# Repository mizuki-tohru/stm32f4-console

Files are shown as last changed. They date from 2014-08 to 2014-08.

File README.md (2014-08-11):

This project is the palm size console with LCD and a keyboard. 
This uses STM32F4 microcomputer. This supports a 400x240-dot mono LCD, keyboard, CMOS, RS422, and Bluetooth serial communication. Moreover, this supports analog inputs. 
Charge of the li-po battery using USB, and high-speed access to a microSD card are also possible. 
A console carries extended BASIC of a uBASIC base. BASIC supports access to the FAT filesystem to microSD, bitmap drawing, analog inputs, and serial port input and output. 

このプロジェクトは、LCDとキーボードを持つ、てのひらサイズのコンソールを自作する試みです。
STM32F4マイコンを用い、400x240ドットモノクロ液晶とキーボード、CMOS、RS422、そしてBluetoothシリアル通信をサポートします。また3チャンネルのアナログ入力をサポートします。
USBコネクタを用いたリチウムポリマバッテリの充電と、microSDカードへの高速なアクセスも可能です。
コンソールはuBasicベースの拡張BASICを搭載します。BASICからmicroSDへのFATバイルシステムへのアクセス、ビットマップ描画、アナログ入力及びシリアルポート入出力をサポートします。

フォント作成にはrubyと東雲フォントが必要です。単体テスト用にcunitを使用していますが、テストを行わないのであれば必要ありません。

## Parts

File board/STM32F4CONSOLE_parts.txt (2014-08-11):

U1       	STM32F405RGT6  		MPUARM Cortex-M4 64Pin 		Digi-key	1184円
U2       	DM3AT-SF-PEJ		MicroSDカードソケット		秋月	140円
U4      	TAR5SB33      		3.3Vレギュレータ			秋月	10個280円
U6			FH12-10S-0.5SH     	液晶コネクタ				Digi-key	217円
D1			SS2040FL			ショットキーバリアダイオード秋月	20個300円
D2,D3,D4,D5,D6	
			1SS352    	    	ショットキーバリアダイオード秋月	40個200円
								
X1       	MUSB-5B-NE-S175		USBminiB基板実装コネクタ	秋月	2個100円
L1,L2,L3,L4 BLM21PG331			チップインダクタ			秋月	25個100円
Q1       	8MHz           		水晶発振子HC49/S型			秋月	10個400円
Q2       	32.768kHz      		水晶発振子TC26H型			秋月	4個100円
								
LED1,2,3						チップLED 0603				秋月	20個200円
Push SW1～43	                SKRPACE010 タクトスイッチ	秋月	5個100円
C1,C2    	22pF           		積層セラミックコンデンサ　0603 千石	10個50円
C3,C4    	5pF            		積層セラミックコンデンサ　0603 鈴商	10個100円
C9,C16,C20,C23,C25,C26,C27,C28	
			0.01uF      		積層セラミックコンデンサ　0603 千石	10個50円
C5,C10,C11,C17,C29	
			0.1uF          		積層セラミックコンデンサ　0603 千石	10個50円
C39      	0.33uF         		積層セラミックコンデンサ　0805 鈴商	10個100円
C8			1uF            	 	積層セラミックコンデンサ　0603 秋月	100個200円
C13,C18,C19 1uF            		積層セラミックコンデンサ　2012 鈴商	10個100円
C6,C7,C15   2.2uF          		積層セラミックコンデンサ　0805 鈴商	10個100円
C14			4.7uF				積層セラミックコンデンサ　2012 秋月	40個200円
C30			10uF           		積層セラミックコンデンサ　3216 秋月	8個100円
C12			47uF           		積層セラミックコンデンサ　3225 秋月	5個200円
								スライドスイッチ			千石	70円
R5,R6,R7,R8,R9,R10	
			22Ω             	抵抗 	603					千石	10個50円
R24,R25		33Ω				抵抗 	603					千石	10個50円
R2,R3    	27Ω           		抵抗 	603					千石	10個50円
R29,R38,R39,R42,R43,R45
		 	100Ω          		抵抗 	603					千石	10個50円
R16,R18  	150Ω          		抵抗 	603					千石	10個50円
R1,R22      220Ω          		抵抗 	603					千石	10個50円
R23,R31		470Ω          		抵抗 	603					千石	10個50円
R21			510Ω          		抵抗 	603					千石	10個50円
R27,R28		1kΩ          		抵抗 	603					千石	10個50円
R4			1.5kΩ         		抵抗 	603					千石	10個50円
R38,R39  	2.7kΩ         		抵抗 	805					鈴商	10個100円
R19      	5.1kΩ         		抵抗 	603					千石	10個50円
R20,R26,R30 10kΩ          		抵抗 	603					千石	10個50円
R11,R12,R13,R14,R15,R17	
			51kΩ          		抵抗 	603					千石	10個50円

								液晶 LS027B4DH01			秋月	3000円
								バッテリ					
								ボタン電池 1220型もしくは1225型			
U$2			RN42		B		luetoothモジュール					1500円
U5			SN65HVD30			453円

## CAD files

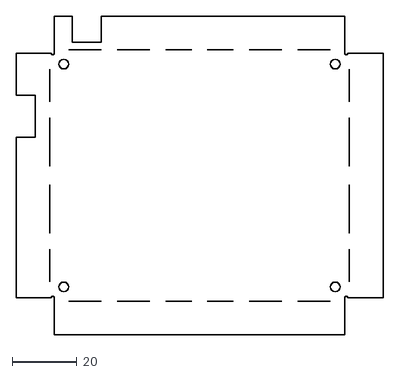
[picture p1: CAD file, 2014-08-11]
board/console_cover_lasercut.dxf
113.6 x 98.6

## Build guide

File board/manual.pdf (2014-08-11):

# "てのりマイコン" STM32F4-Console マニュアル

# 1:"てのりマイコン"について

てのりマイコン STM32F4-Console は、32 ビットマイコン、43 キーのキーボード、USB インタフェイス、マイクロ SD コネクタ、BASIC インタプリタ、シリアルモニタ、3 チャ ンネルの ADC 入力を搭載し、モノクロ 400x240 解像度ビットマップ液晶と、USB から充電できるバッテリーを搭載可能な、てのひら動作をするマイコンです。 BASIC インタプリタはエディタ内蔵で、どこでもプログラミングが可能です。BASIC からマイクロ SD 中のファイルを読み書きすることも、シリアル通信を制御することもで きます。
本基板には更に Bluetooth モジュールと RS-422 シリアル通信インタフェイスが増設可能です。Bluetooth モジュールは他の Bluetooth 機器と SPP で通信します。 それらを実装されたい方は、別紙の組み立て説明書に従って、部品を入手して半田付けしてください。また RS-422 インタフェイスも増設可能となっています。

## 2:必要な部品

以下の部品をはんだ付けしてください。
| 品名 | 種類 | サイズ | 購入先 | 価格
U1 | STM32F405RGT6 | MPUARM Cortex-M4 64Pin | | Digi-key | 1184 円
U3 | MAX1555 | LiPo バッテリ充電制御 IC | | Digi-key | 251 円
U4 | TAR5S33 | 3.3V レギュレータ | | 秋月 | 10 個 280 円
D1 | MBR0520LT | ショットキーバリアダイオード | | 秋月 | 20 個 300 円
D2,D3,D4,D5,D6 | 1SS352 | ショットキーバリアダイオード | | 秋月 | 40 個 200 円
U2 | DIM3AT-SF-PEJ | MicroSD カードソケット | | 秋月 | 140 円
X1 | MUSB-5B-NE-S175 | USB MiniB 基板実装コネクタ | | 秋月 | 2 個 100 円
L1,L2,L3,L4 | BLM21PG331 | チップインダクタ | | 秋月 | 25 個 100 円
Q1 | 8MHz | 水晶発振子 HC49/S 型 | | 秋月 | 10 個 400 円
Q2 | 32.768kHz | 水晶発振子 TC26H 型 | | 秋月 | 4 個 100 円
U6 | FH12-10S-0.5SH | 液晶フラットケーブルコネクタ | | 秋月(液晶に付属) | 3000 円
LED1,2,3 | | チップ LED | 1608 | 秋月 | 20 個 200 円
PushSW 1～43 | SKRPACE010 | タクトスイッチ | | 秋月 | 5 個 100 円
C1,C2 | 22pF | 積層セラミックコンデンサ | 1608 | 千石 | 10 個 50 円
C3,C4 | 7pF | 積層セラミックコンデンサ | 1608 | 鈴商 | 10 個 100 円
C9,C16,C20,C23,C25,C26,C27,C28 | 0.01uF | 積層セラミックコンデンサ | 1608 | 千石 | 10 個 50 円
C5,C10,C11,C17,C29 | 0.1uF | 積層セラミックコンデンサ | 1608 | 千石 | 10 個 50 円
C39 | 0.33uF | 積層セラミックコンデンサ | 2012 | 鈴商 | 10 個 100 円
C8 | 1uF | 積層セラミックコンデンサ | 1608 | 秋月 | 100 個 200 円
C13,C18,C19 | 1uF | 積層セラミックコンデンサ | 2012 | 鈴商 | 10 個 100 円
C6,C7,C15 | 2.2uF | 積層セラミックコンデンサ | 2012 | 鈴商 | 10 個 100 円
C14 | 4.7uF | 積層セラミックコンデンサ | 2012 | 秋月 | 40 個 200 円
C30 | 10uF | 積層セラミックコンデンサ | 3216 | 秋月 | 8 個 100 円
C12 | 4.7uF | 積層セラミックコンデンサ | 3225 | 秋月 | 5 個 200 円
R5,R6,R7,R8,R9,R10 | 22Ω | 抵抗 | 1608 | 千石 | 10 個 50 円
R24,R25 | 33Ω | 抵抗 | 1608 | 千石 | 10 個 50 円
R2,R3 | 27Ω | 抵抗 | 1608 | 千石 | 10 個 50 円
R29,R38,R39,R42,R43,R45 | 100Ω | 抵抗 | 1608 | 千石 | 10 個 50 円
R16,R18 | 150Ω | 抵抗 | 1608 | 千石 | 10 個 50 円
R1,R22 | 220Ω | 抵抗 | 1608 | 千石 | 10 個 50 円
R23,R31 | 470Ω | 抵抗 | 1608 | 千石 | 10 個 50 円
R21 | 510Ω | 抵抗 | 1608 | 千石 | 10 個 50 円
R27,R28 | 1kΩ | 抵抗 | 1608 | 千石 | 10 個 50 円
R4 | 1.5kΩ | 抵抗 | 1608 | 千石 | 10 個 50 円
R38,R39 | 2.7kΩ | 抵抗 | 2012 | 鈴商 | 10 個 100 円
R19 | 5.1kΩ | 抵抗 | 1608 | 千石 | 10 個 50 円
R20,R26,R30 | 10kΩ | 抵抗 | 1608 | 千石 | 10 個 50 円
R11,R12,R13,R14,R15,R17 | 51kΩ | 抵抗 | 1608 | 千石 | 10 個 50 円

その他、動作には液晶と LiPo バッテリが必須です。USB をつないだ状態でも動作しますが、それではあまり面白くないでしょう。本マイコンはカレンダークロックを 持っていますが、これを使うためには 1220 か 1225 のボタン電池と電池ホルダが必要です。
秋月電子で売っている、シャープ製液晶 LS027B4DH01 を、基板背面のフラットケーブルコネクタに接続します。このとき液晶は表面を向けた状態で接続しましょう。 リボンケーブルを曲げて液晶を基板前面に持ってきて、ここで液晶を固定します。そのために液晶に両面テープを貼っておくといいでしょう。基板前面には MPU や OP アンプなど部品があり段差になりますから、これら段差をカバーするような厚みのある両面テープを重ねて使うことになるでしょう。 フラットケーブルがきちんと接続していれば、USB ケーブルを刺せば液晶に初期メッセージが表示され、BASIC インタプリタの入力待ちになる筈です。
1 セルのリチウムイオンかリチウムポリマ二次バッテリならどれでも使えます。定格 3.7V 以上なら他のバッテリでも動きますが充電はリチウム二次電池しか対応しません。 基板表面右上/裏面左上の BATT 端子にバッテリを接続します。極性を間違えないでください。POWER スイッチを左に動かし、USB Mini-B コネクタにケーブルを接 続して充電します。充電中は基板裏の赤 LED が点灯しています。消灯したら充電終了です。
秋月電子で売っているものや、aitendo で売っている同じような電池ホルダを JP15/JP16 にはんだ付けします。ボタン電池を入れると、この電池が電源を切っても内蔵カ レンダーの内容を保持します。

ケース:
このマニュアルの最後に、板を切って曲げるタイプのケースの工作図面があります。組み立てには 7～8 ミリ程度の長さのスペーサー 4 本が別途必要になります。

その他部品:
本基板は、裏面に Bluetooth モジュールを半田付けして、Bluetooth を使えるようにすることができます。その他 RS-422 通信も部品追加で可能になります。Bluetooth モジュール RN42 は、秋月電子で 1500 円で売っているものが使えます。

## 3:実装に関しての注意

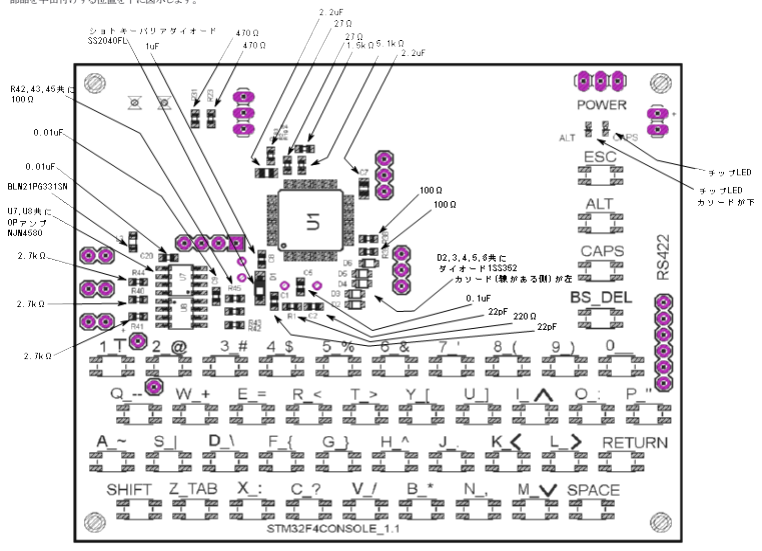
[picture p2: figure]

部品を半田付けする位置を下に図示します。

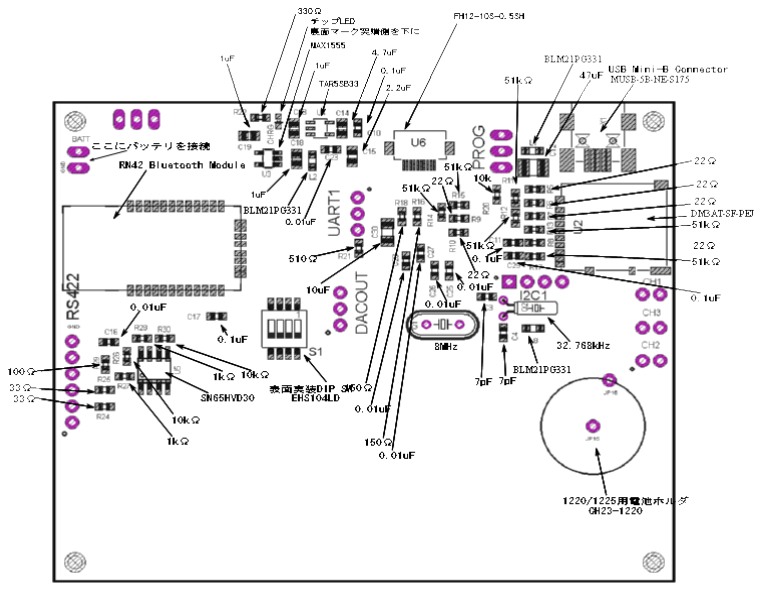
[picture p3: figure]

## 4:プログラムの入手と書き込み

基板へ部品を実装したら、プログラムを書き込みましょう。　その為にはまずプログラムを書き込む環境を整えなければいけません。4.1 ではそれを説明します。 プログラムは用意されたものを書き込む方法と、自分でプログラムのソースコードとコンパイル環境を整え、自作する方法の 2 つがあります。まずは前者を 試してください。これも 4.1 で説明しています。後者は 4.2、4.3 で説明します。自作することによって自由に機能を追加、改変することができるようになります。

### 4.1:プログラムの書き込み

Windows ユーザは以下の URL より書き込み用のツール DfuSe をダウンロード、インストールしてください。 STSW-STM32080:DfuSe USB device firmware upgrade STMicroelectronics extension
http://www.st.com/web/jp/catalog/tools/PF257916
書き込みに使うツールは DfuSe Demonstration です。
プレーヤ基板を USB ケーブルで PC と接続し、電源スイッチと Program スイッチを入れてください。ドライバのインストールが始めれば、マイコンとその周辺回路の半田 づけはうまくいっています。ドライバのインストールが終わったら、DfuSe を起動します。
プレーヤ基板は OS から、STM Device in DFU mode として認識されます。DfuSe のウィンドゥ左上にも同様の表示がある筈です。次いで下部中央の Choose..ボタンを 押して、書き込むファイルを選択します。
書き込むファイルは、以下の URL よりダウンロードしてください。

選択したら、DfuSe の画面、さっきのボタンのすぐ右、Upgrade のボタンを押してください。書き込みと、正しく書けたかを検査するベリファイが行われます。正常終了で、 書き込みは成功、終了です。電源スイッチを落とし、Program スイッチを動作側にしてください。

Unix(linux,Mac)ユーザは、dfu-util を使います。

http://dfu-util.gnumonks.org/
サイトの指示に従って環境を構築してください。書き込むファイルは同じです。

### 4.2:プログラムソースの入手とコンパイル

プログラムのコンパイルには GCC コンパイラを使用します。Windows ユーザはまず Cygwin 開発環境を整えてください。Windows ユーザも Cygwin 環境を使うことで、 以下の説明も Unix ユーザと同様に実行できます。

## 4.2.1:Cygwin の導入

Cygwin 導入には、
http://cygwin.com/
で Setup.exe をダウンロードし、実行することで好きなモジュールごとに選んでインストールすることになります。また Setup.exe を使うことで最新版へのアップデートも可 能となります。
Setup.exe を実行し、[install from internet]を選択すると、インストールするディレクトルを聞かれます。ここはできるだけデフォルトの[C:\cygwin]のままで。 Install For は[All Users],Default Text file Type は[Unix]に。

インストールは、まず選択したパッケージファイルを指定したテンポラリディレクトリに展開してから行われます。Local Packege Directory はその指定です。 Select Your Internet Connection は[Direct connection]で。
Choose A Downloads site で、ダウンロード先を選択します。

Select Packages で、好きなパッケージを選んでインストールします。 Bin?は実行可能なバイナリ、Src?はソースコードを意味します。 この時点で、Cygwin システムとして必要最小限のパッケージが選択されています。 開発環境としてあと必要なのは、
+All
+Base <= Bin?全てを選択する
+Devel <= 以下のものの Bin?,Src?双方を選択する
gcc binutils flex bison libgmp3-dev libmpc-dev libmpfr-dev libncurses5-dev +InterPreters <= gawk,m4,perl の Bin?を選択 あとは好きなものを。CVS,Subversion,git は選択べきです。

+Devel で選択する GCC は 4.*系列を選びましょう。ソースも忘れずに。

インストールが終了すると、デスクトップに Cygwin のアイコンが出来るのでダブルクリックして起動します。 見かけは DOS コマンドプロンプトに似ていますが、Unix 環境です。ためしに ls や cat を実行してみてください。

## 4.2.2:Newlib の導入

newlib は組み込み用の C/C++ライブラリです。
newlib はさっきの Cygwin のサイトからジャンプしたサイトからダウンロードできます。サイト左端のリンクリスト一番下の[sources.redhat.com] http://sources.redhat.com/
再び左端の[Prejects]
http://sources.redhat.com/projects.html
下のほうの[newlib]
http://sources.redhat.com/newlib/ <=最初からここへ行くも良し
左端の[Download]から Source snapshot をとって来ます。一番下の文章中の[newlib ftp directory]というリンクの先から、一番新しいものをダウンロードしてきます。 *もちろん、CVS で落とすのも OK
ダウンロードしたファイルは C:/Cygwin/usr/src にコピーします。
解凍は Cygwin 環境で行います。まず cd /usr/src　で、ダウンロードしたファイルの位置に飛びます。Cygwin の中では、C:\Cygwin が　/　つまりルートディレクトリとなり ます。
tar -zxvf newlib-2.1.0.tar.gz
これで解凍されます。

## 4.2.3:binutils の準備

/usr/src には、ソースコードのダウンロードを選択したパッケージが、既に展開されていると思います。
その中に cd し、次のようなコマンドを実行します
./configure --target=arm-m4-eabi --prefix=/opt/stm32-tools/ --enable-interwork --enable-multilib --disable-nls --disable-libssp

configure コマンドは環境に応じてコンパイルの下準備をします。
-target オプションは ARM アーキテクチャの elf バイナリ版を作るということを意味しています。elf についてはここでは触れません。
-prefix オプションは、クロスコンパイル環境をどこに構築するかを示します。ここでは/usr/cross を推奨します。先にディレクトリを作っておきましょう。 mkdir /usr/cross
-disable-nls は多言語対応オプションを外すことを意味しています。
次に、
make
を実行します。無事終了したら(しばらくかかります)、
make install
を実行します。

## 4.2.4:GCC の準備

/usr/src/gcc-4.*.* へ cd します。
まず、newlib へのシンボリックリンクを張ります。まぁ、ショートカットみたいなもんです。 ln -s ../newlib-2.1.0/newlib .

コンパイル先ディレクトリを掘ります。

mkdir dist
cd dist
コンフィギュレーションを行います。
../configure --target=arm-m4-eabi --prefix=/opt/stm32-tools/ --enable-interwork --enable-multilib -with-gmp=/usr/local -with-mpfr=/usr/local -with-mpc=/uar/local --enable-languages="c" --with-newlib --with-headers=../../newlib-2.1.0/newlib/libc/include/ --disable-libssp --disable-nls
そして、
make CFLAGS_FOR_TARGET="-mcpu=cortex-m4 -mthumb -mfloat-abi=softfp -mfpu=fpv4-sp-d16"
make install
dist ディレクトリの中身を消去(make clean ではうまくいかない場合があった)し、再度コンフィギュレーションを行います。
../configure --target=arm-m4-eabi --prefix=/opt/stm32-tools/ --enable-interwork --enable-multilib -with-gmp=/usr/local -with-mpfr=/usr/local -with-mpc=/uar/local – enable-languages="c,c++" --with-newlib --with-headers=../../newlib-2.1.0/newlib/libc/include/ --disable-libssp --disable-nls
make CFLAGS_FOR_TARGET="-mcpu=cortex-m4 -mthumb -mfloat-abi=softfp -mfpu=fpv4-sp-d16" CXXFLAGS="-mcpu=cortex-m4 -mthumb -mfloat-abi=softfp -mfpu=fpv4-sp-d16" all
make install
これで GCC が C++まで使用可能となります。

### 4.2.2:プログラムソースの準備

バージョン管理ツール Git を使い、Github サイトから以下のようなコマンドでプログラムソースを取得してください。

## git clone https://github.com/mizuki_tohru/stm32f4-console stm32f4-console

以後もデバッグ、アップデートの度にプログラムソースは更新されますので、最新版(や過去のバージョン)を Git を使って取得してください。

### 4.2.3:必要なライブラリソースの準備

以下のようなライブラリが必要になります。

STM32F4 のライブラリ
STSW-STM32065 STM32F4 DSP and standard peripherals library を以下の URL より入手してください。
http://www.st.com/web/catalog/tools/PF257901
STM32F105/7, STM32F2 and STM32F4 USB on-the-go Host and device library (UM1021) から USB 関連ライブラリを選りだして上のライブラリにコピーしてください。 http://www.st.com/web/catalog/tools/PF257882

東雲フォントと NKF ライブラリ(漢字を使う場合)
http://openlab.jp/efont/dist/shinonome/
から、shinonome-0.9.11p1.tar.bz2 を入手して makefile の示す位置に展開しておいてください。
漢字を使用する場合 libnkf により文字コード対応を行いますが、libnkf-1.0.0.tar.gz の配布が中止されたようなので、他の libnkf 実装を試してみてください。

fatff 他ライブラリについて、ねむいさんのブログより以下のライブラリを入手してください。
TFT/OLED Control Sample with ChaN's FatFs(SDIO&MMC Driver)
http://nemuisan.blog.bai.ne.jp/?eid=192848

### 4.2.4:プログラムのコンパイル

プログラムソースの位置はは gcc やライブラリにパスが通っている必要があります。パスが通っていなければ、makefile で直接指定してください。 取得したライブラリのバージョンが makefile に書かれているものと食い違っている場合があります。実際に取得したライブラリのバージョンにあわせて makefile は書き換 えて下さい。
コンパイルに成功すると様々なファイルが生成されますが、使用するのは main.s19 です。これを DfuSe ツールの中の DFU File manager で拡張子 dfu のファイルに変 換し、4.1 で説明した手順でこれをボード上のマイコンに書き込みます。

## 5:動作について

右上 POWER スイッチは、バッテリーからの給電と USB からの給電、この 2 つの給電方式を切り替えるスイッチです。右がバッテリーから、左が USB からになります。 使い初めや充電が必要な場合は、まず POWER スイッチを左にスライドさせて USB-MiniB コネクタを接続してください。基板裏で赤い LED が光ります。これが消 えると充電完了です。そのまま USB コネクタを引き抜いてください。
USB ケーブルが接続していない状態で、POWER スイッチを右にスライドさせると動作開始です。てのりマイコンはマイクロ SD カードが刺さっていればこれを検査し た後、BASIC インタプリタを起動します。OK と表示されて、キー操作ができるようになります。
キーボードはシンクレア ZX スペクトラムのものを一部アレンジしたものになっています。右上の 2 つの LED が両方とも消灯しているときは、キーボードは印刷左側、 数字とアルファベット、但し小文字を出力します。SHIFT キーを押しながら他のキーを押すと大文字が出力されます。また、CAPS キーを押すと LED 右側が点灯し、 大文字が打てるようになります。更にもう一度 CAPS キーを押すと LED は消灯し、小文字に戻ります。
ALT キーを押すと、左側の LED が点灯し、キーボードの印刷右側が打てるようになります。更にもう一度押すと LED は消灯し、キーは元の数字とアルファベットの 配列に戻ります。ALT キーと CAPS キーが双方とも押された場合、ALT キーのほうが優先されます。
BS_DEL キーはアルファベットが小文字を打てるときはバックスペース、大文字を打てるときはデリートキーとして働きます。このキーは ALT キーを無視します。 ESC キーを押すと、BASIC インタプリタを終了し、シリアルモニタに動作を切り替えます。更に押すとアナログモニタに動作は切り替わります。更に押すと日付時刻設 定モードになりますので、事前に 1220 または 1225 ボタン電池を基板裏の電池ホルダに入れてから、日付時刻の設定をおこなってください。 日付時刻設定モードから更に ESC キーを押すと、BASIC インタプリタに動作は再び戻ります。

日付設定の仕方
カーソルキーの左右(K_<,L_>)でカーソルを移動して、カーソルの上下(I_↑,M_↓)で値を変更します。値を確定したら、RETURN キーを押してください。それで値 が設定されます。

シリアルモニタ
プログラムはデフォルトでは UART1 の入出力をサポートしています。Bluetooth モジュールを使う際は、UART6 を替わりに有効化してください。 受信内容はリアルタイムで表示され、キーで入力された内容はリターンキーで送信されます。初期値は 115200bps ｍ 8 ビット、ノンパリ、ストップビット 1 です。

アナログモニタ
液晶左下付近に 2 ピンのスルーホールが 3 つ並んでいますが、ここに端子を接続して外部電圧を測定、表示することができます。表示されるのは(今のところ)ch1 と ch2 の二つです。スルーホールと ch の関連は基板裏側のシルクを見て確認してください。
電圧は 3.3V まで入力できます。(入力する OP アンプにはレールツーレールタイプを使っています。)ピンは外側が GND、内側が電圧入力になります。

BASIC インタプリタ
BASIC インタプリタは uBASIC(dunkels.com/adam/ubasic)に拡張を加え、エディタを追加したものです。横 50 文字、256 行まで(メモリには 12kbyte まで)の記
述ができます。

変数には 16 ビット整数及び 32 ビット整数、文字列型と配列が使用できますが、使用できる数と名前には制限があります。変数は全てアルファベット小文字 a から z、 大文字 A から N までの 40 種のみとなります。種別は以下の通りです。
a-z | 整数型 16 ビット符号付き整数。
A,B,C,D | 配列型 16 ビット整数を最大長 2048 個まで保持できる。
E,F,G,H | 文字列型 8 ビット整数を最大長 4096 個まで保持できる。
I,J,K,L,M,N 大整数型 32 ビット符号付き整数。
変数は使用前に LET 文で宣言をおこなわなければいけません。行わなかった場合動作は不定です。

### let 文

構文: let 変数名
例:
100 let a
120 a = 100

BASIC の各行には行番号が必要です。実行は行番号の若いものから順におこなわれます。行番号の無い行はリターンキーでその行は即時実行されます。

### 制御構文として if-then、for-to-next、goto、gosub、return、call、end があります。

### if-then 文 構文: if 条件 then 処理

例:
100 if a > 10 then goto 200
110 print “little”

### for-to-next 文

構文: for ループ変数初期化 to ループ終了値 値増加は 1 づつ ループされる処理
next ループ変数
例:
100 for a = 0 to 100
110 print a
120 next a

### goto 文

行番号の位置まで飛ぶ。
例:
100 goto 200

### gosub-return 文

行番号の位置まで飛び、実行中に return に遭遇したら gosub の位置まで戻ってくる。 例:
100 gosub 200
110 print “second”
120 end
200 print “first”
210 return

### end 文

BASIC プログラムの動作を終了して、エディタの入力画面に戻ります。 例:
100 print “end”
110 end

### run 命令

run は行番号なし行でしか実行されない。run 文が実行されると、行番号つき BASIC の各行が一番若い行から順に実行される。 例:
run

### list 命令

list は行番号なし行でしか実行されない。list 文が実行されると、行番号つき BASIC の各行が一番若い行から順に出力される。 例:
list

### files 命令

files は行番号なし行でしか実行されない。files 文が実行されると、SD カード内のファイルの一覧が表示される。 例:
files

### rem 文

rem はコメント文で、この文から行末までインタプリタには実行されない。 例:
100 print “hoge” rem hogehogehogehoge

### pset 文

pset 文は画面に点を打つ。
構文 pset x y 1 (1 で黒点、0 で白点) x は 0 から 399 まで、y は 0 から 239 まで。左上が画面原点。 例:
100 let x
110 x = 100
120 pset x 100 1

refresh 文
refresh は画面を更新する。pset 文は画面に転送する前のイメージバッファを更新するが、画面への転送をそのタイミングでは行わない。refresh 文は強制的にイメージ バッファを画面へと転送する。
例:
100 refresh

### cls 文

cls 文は画面を消去する。
例:
100 cls
例:
cls

### load 文

load 文は SD カードから指定のファイルをロードする。拡張子が BAS のものは内容をプログラムとしてロードする。ファイル名はダブルクォーテーションで囲わなけれ ばならない。
拡張子が TXT のものは内容を文字列型変数 H に読み込む。但し 4096 バイトまでしか読み込むことはできない。
拡張子が DAT のものは内容を配列型変数 D に読み込む。このときファイル内容をバイナリデータとみなして先頭から 4 キロバイトまでを読み込む。
拡張子が BMP のものは Windows ビットマップ 2 値イメージファイルとみなして読み込み後画面表示をおこなう。この際先に表示されていた内容はすべて消去され る。ファイルは 400x240 ビットのモノクロ二値データでなければならない。
例:
load "hoge.bas"

### save 文

save 文は SD カードへ指定のファイル名で書き込む。拡張子が BAS のものはエディタで編集中の行番号付プログラムが格納される。同名のファイルが存在した場 合は上書きされる。
拡張子が TXT のものは、文字列型変数 H の内容を文字列終端もしくは 4096 バイトまで指定のファイルに書き込む。同名のファイルが存在した場合は上書きされる。 拡張子が DAT のものは、配列型変数 D の内容を終端もしくは 4096 バイトまで指定のファイルに書き込む。同名のファイルが存在した場合は上書きされる。 拡張子が BMP のものは、現在のスクリーンショットを指定のファイルに書き出す。同名のファイルが存在した場合は上書きされる。
例:
save “hogehoge.bas”

### wait 文

wait 文は指定ミリ秒間動作を停止する。
例:
100 wait 100

### input 文

input 文は キーボードから入力を受け取る文である。 代入変数は文字列型、改行コードが出るまで、または変数が一杯になるまで動作する。 例:
100 let E
120 E = input

### inp 文

inp 文は キーボードから入力を一文字だけ受け取る文である。キーボードからひと文字受け取るまで入力待ちをする。 例:
100 let a
110 a = inp

### inr 文

inr 文は キーボードから入力を受け取る文である。入力待ちを行わず、呼び出すと直近のキーボード入力ひと文字を返す。 例:
100 let a
110 a = inr

### ina 文

ina 文は ADC アナログ入力を受け取る文である。

### 構文 a = ina 1 (=チャンネル番号 0,1,2)

例:
100 let a
110 a = ina 1

### print 文

print 文は指定の文字列を出力する。文字列型変数も出力できる。 例:
100 print "good hoge\n"
110 print E

演算子として +,-,*,/,%,&,|,>,<,=,がある。結合制御に()が使用できる。 演算子に優先順位は無い。

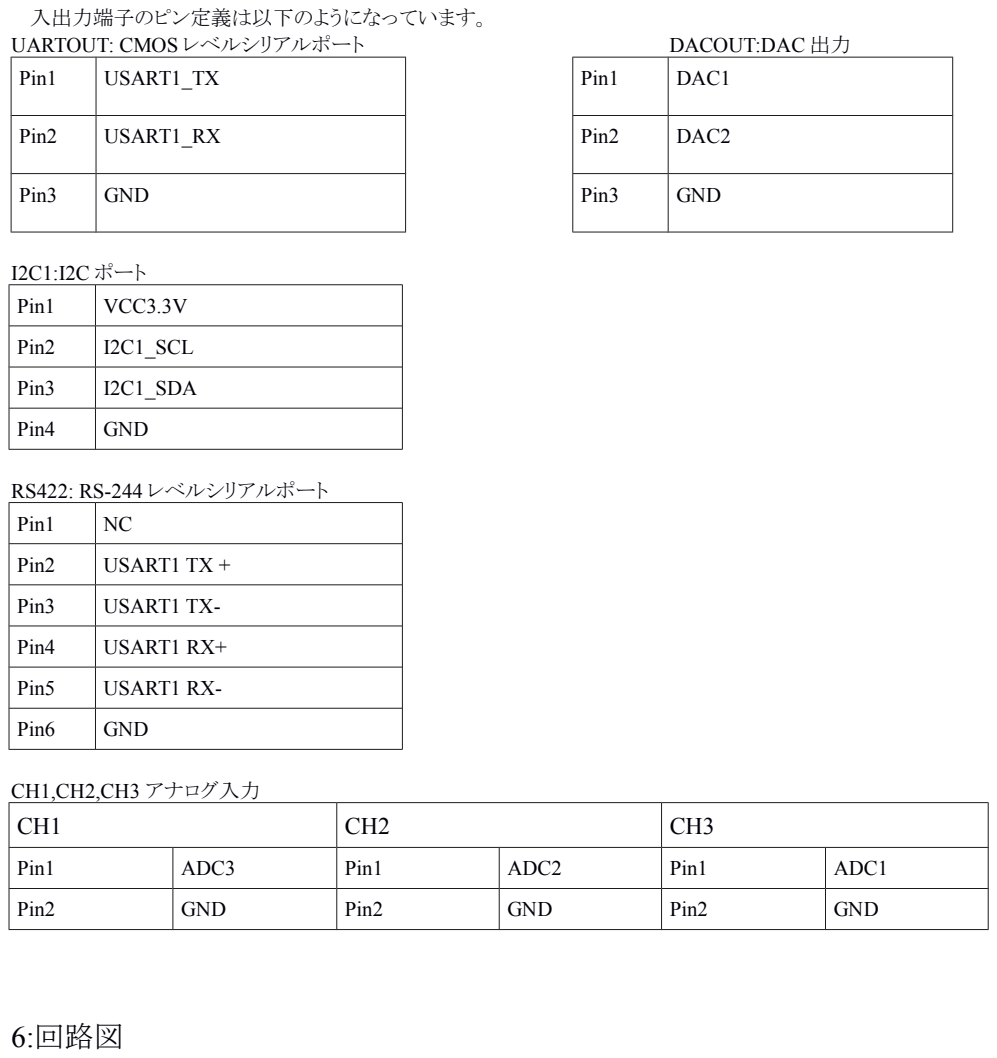
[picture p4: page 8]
入出力端子のピン定義は以下のようになっています。; UARTOUT: CMOS レベルシリアルポート; DACOUT:DAC 出力; I2C1:I2C ポート; RS422: RS-244 レベルシリアルポート; CH1,CH2,CH3 アナログ入力; 6:回路図

Pin1 | USART1_TX | Pin1 | DAC1

Pin2 | USART1_RX | Pin2 | DAC2

Pin3 | GND | Pin3 | GND

Pin1 | VCC3.3V
Pin2 | I2C1_SCL
Pin3 | I2C1_SDA
Pin4 | GND

Pin1 | NC
Pin2 | USART1 TX +
Pin3 | USART1 TX-
Pin4 | USART1 RX+
Pin5 | USART1 RX-
Pin6 | GND

Pin1 | ADC3 | Pin1 | ADC2 | Pin1 | ADC1
Pin2 | GND | Pin2 | GND | Pin2 | GND

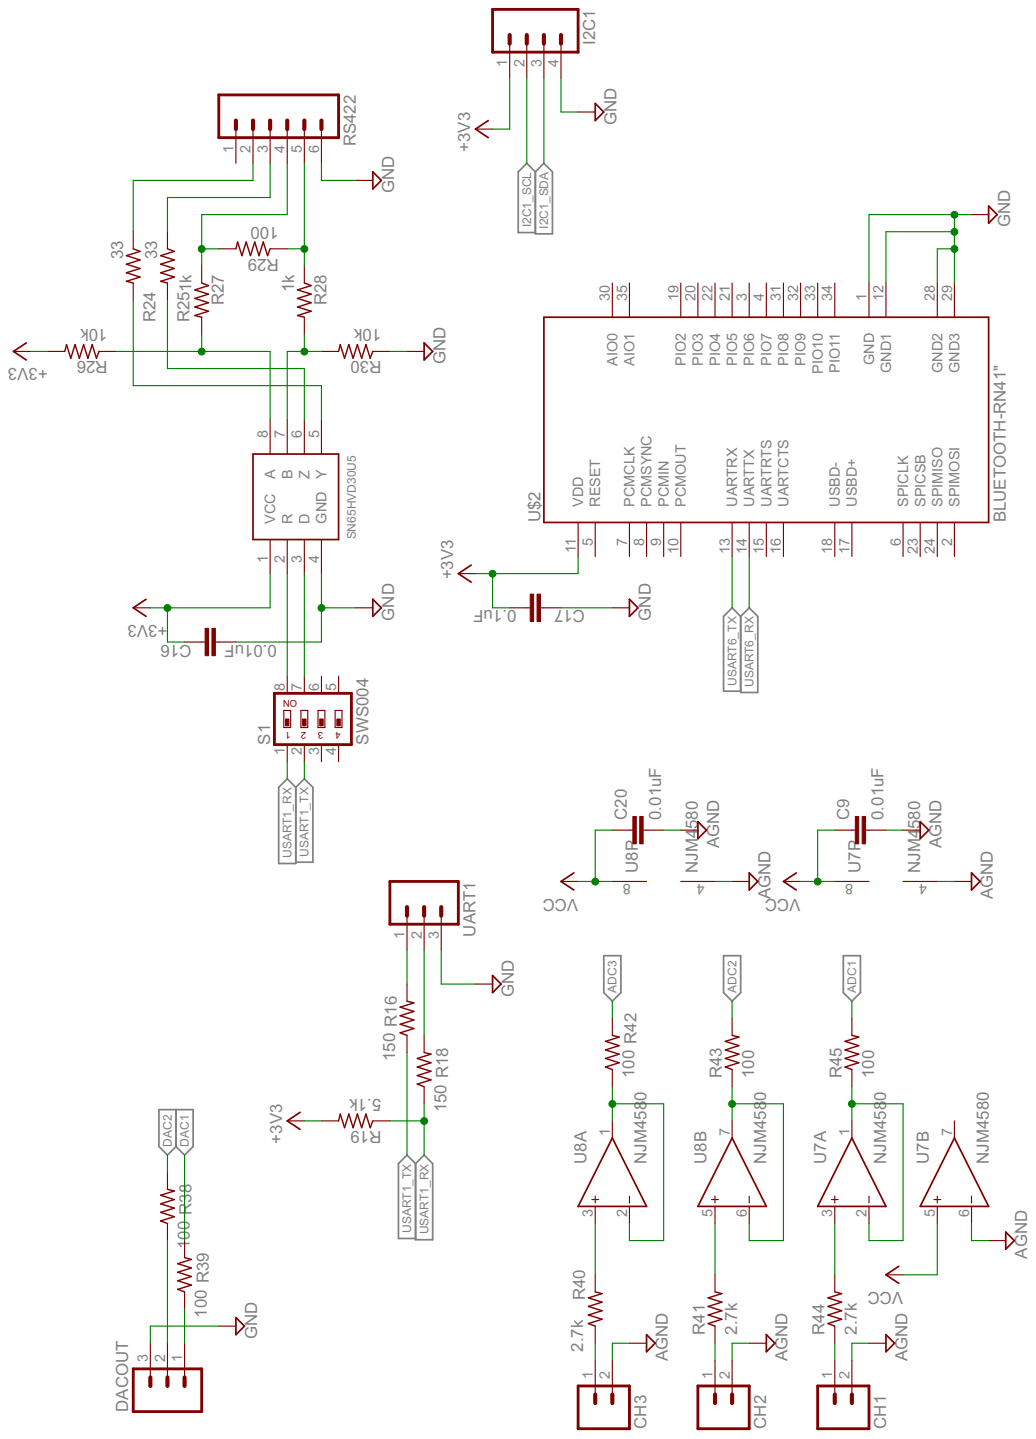
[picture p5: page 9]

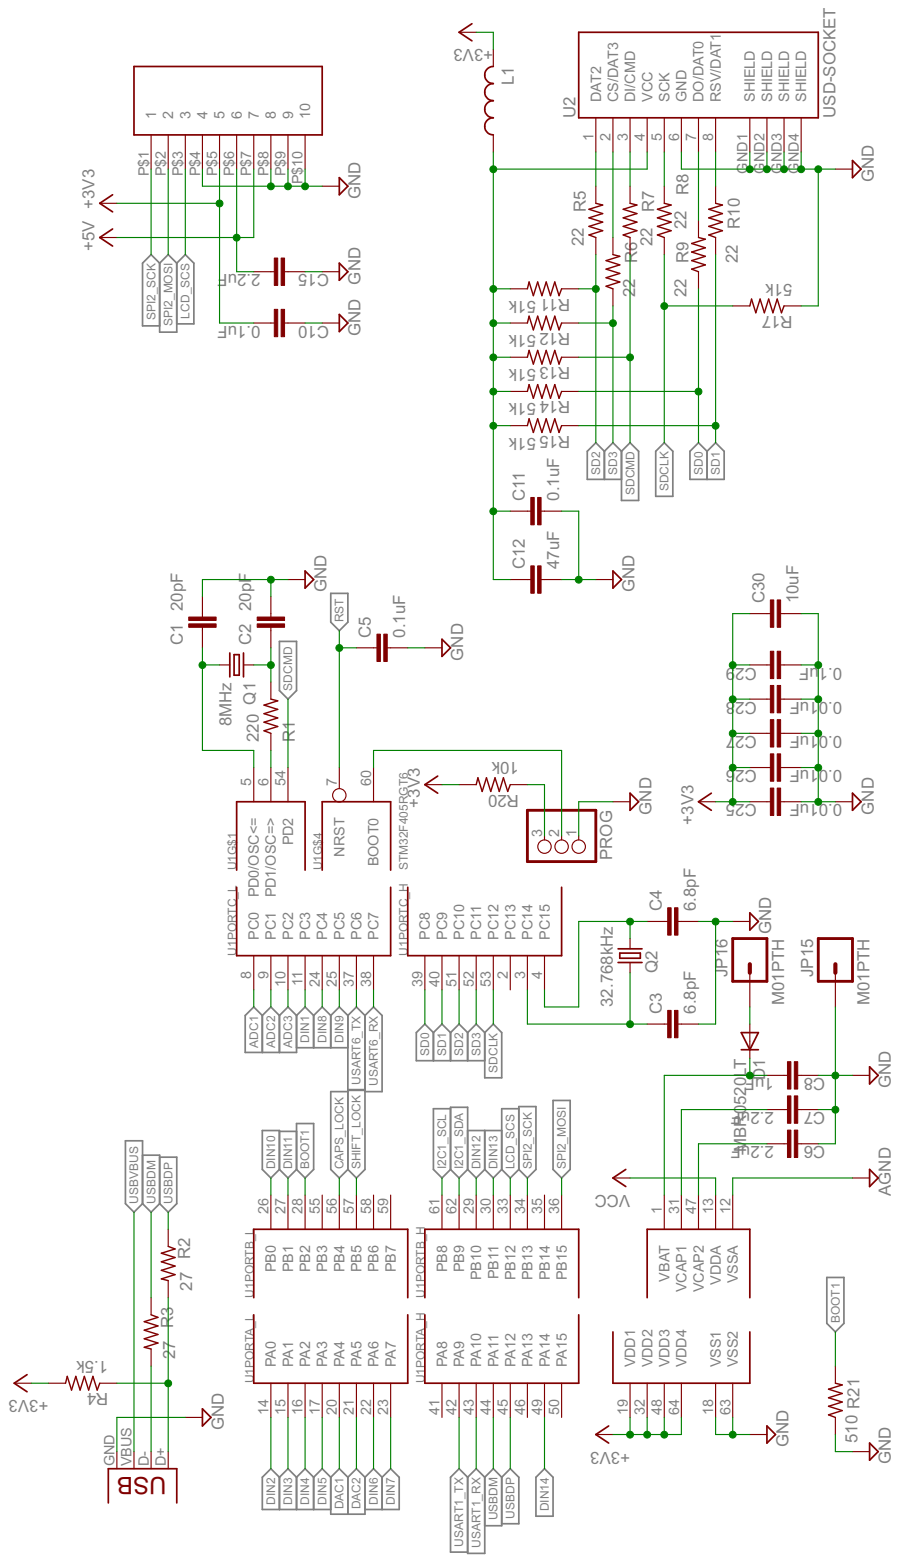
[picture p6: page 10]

SHIELD GND3 SHIELD GND1 SHIELD GND2 SHIELD GND4

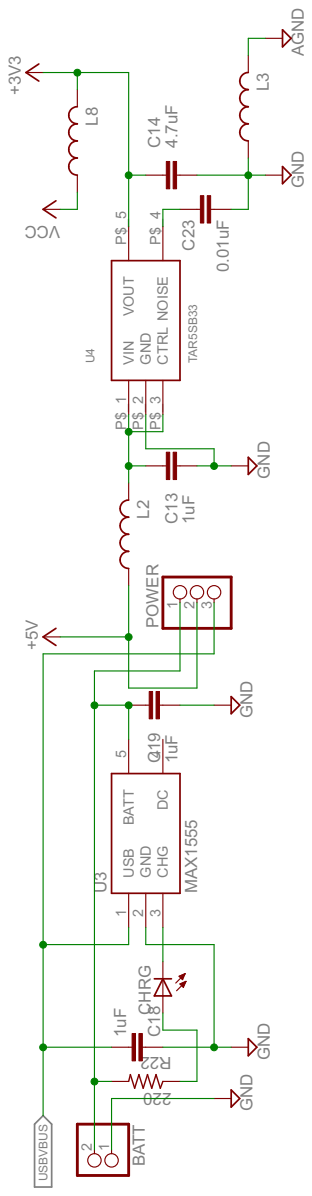
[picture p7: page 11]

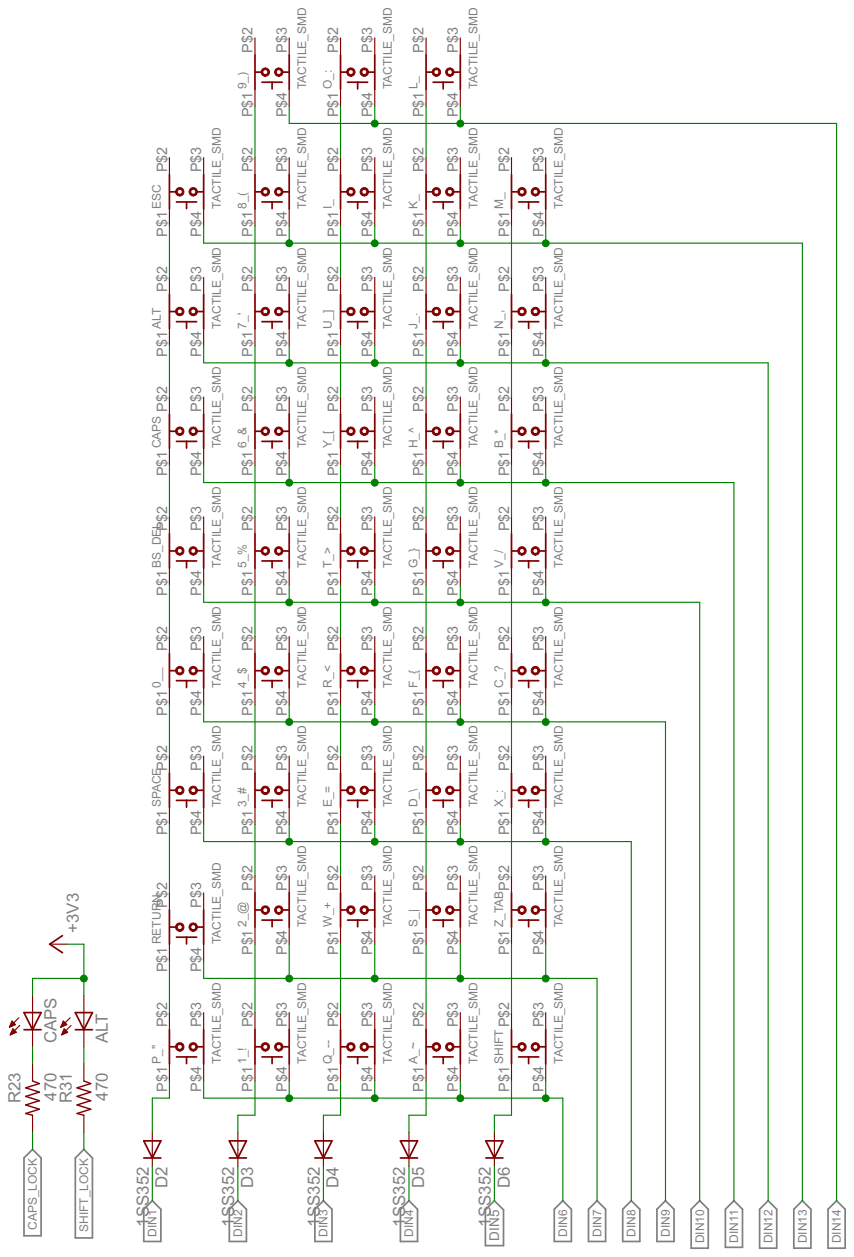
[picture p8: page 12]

+5V GND 1uF 4.7uF +3V3 TAR5SB33 GND 0.01uF AGND CCV GND TACTILE_SMD TACTILE_SMD TACTILE_SMD TACTILE_SMD TACTILE_SMD TACTILE_SMD TACTILE_SMD TACTILE_SMD TACTILE_SMD TACTILE_SMD TACTILE_SMD TACTILE_SMD TACTILE_SMD TACTILE_SMD TACTILE_SMD TACTILE_SMD TACTILE_SMD TACTILE_SMD TACTILE_SMD TACTILE_SMD TACTILE_SMD TACTILE_SMD TACTILE_SMD TACTILE_SMD TACTILE_SMD TACTILE_SMD TACTILE_SMD TACTILE_SMD TACTILE_SMD TACTILE_SMD TACTILE_SMD TACTILE_SMD TACTILE_SMD TACTILE_SMD TACTILE_SMD TACTILE_SMD TACTILE_SMD TACTILE_SMD TACTILE_SMD TACTILE_SMD TACTILE_SMD TACTILE_SMD TACTILE_SMD 1SS352 1SS352 1SS352 1SS352 1SS352 MAX1555 1uF GND 1uF GND 022 470 470 +3V3 BATT 21 POWER 123 C13 C14 L2 U4 VIN P$_1 GND P$_2 CTRL P$_3 VOUT P$_5 NOISE P$_4 C23 L3 L8 P$1 P$2 P$3 P$4 2_@ P$1 P$2 P$3 P$4 3_# P$1 P$2 P$3 P$4 4_$ P$1 P$2 P$3 P$4 5_% P$1 P$2 P$3 P$4 V_/ P$1 P$2 P$3 P$4 6_& P$1 P$2 P$3 P$4 7_' P$1 P$2 P$3 P$4 8_( P$1 P$2 P$3 P$4 M_ P$1 P$2 P$3 P$4 9_) P$1 P$2 P$3 P$4 W_+ P$1 P$2 P$3 P$4 E_= P$1 P$2 P$3 P$4 R_< P$1 P$2 P$3 P$4 T_> P$1 P$2 P$3 P$4 Y_[ P$1 P$2 P$3 P$4 B_* P$1 P$2 P$3 P$4 U_] P$1 P$2 P$3 P$4 I_ P$1 P$2 P$3 P$4 O_: P$1 P$2 P$3 P$4 S_| P$1 P$2 P$3 P$4 D_\ P$1 P$2 P$3 P$4 F_{ P$1 P$2 P$3 P$4 G_} P$1 P$2 P$3 P$4 H_^ P$1 P$2 P$3 P$4 J_. P$1 P$2 P$3 P$4 K_ P$1 P$2 P$3 P$4 RETURN P$1 P$2 P$3 P$4 SPACE P$1 P$2 P$3 P$4 0_ P$1 P$2 P$3 P$4 C_? P$1 P$2 P$3 P$4 BS_DEL P$1 P$2 P$3 P$4 CAPS P$1 P$2 P$3 P$4 ALT P$1 P$2 P$3 P$4 N_, P$1 P$2 P$3 P$4 ESC P$1 P$2 P$3 P$4 P_" P$1 P$2 P$3 P$4 1_! P$1 P$2 P$3 P$4 Q_-- P$1 P$2 P$3 P$4 A_~ P$1 P$2 P$3 P$4 SHIFT P$1 P$2 P$3 P$4 Z_TAB P$1 P$2 P$3 P$4 X_: P$1 P$2 P$3 P$4 L_ D2D3D4D5D6 U3USB 1 GND 2 CHG 3 BATT 5 DC 4 C18 C19 CHRG 22R CAPS ALT R23 R31 USBVBUS DIN1 DIN2 DIN3 DIN4 DIN5 DIN6 DIN7 DIN8 DIN9 DIN10 DIN11 DIN12 DIN13 DIN14 CAPS_LOCK SHIFT_LOCK

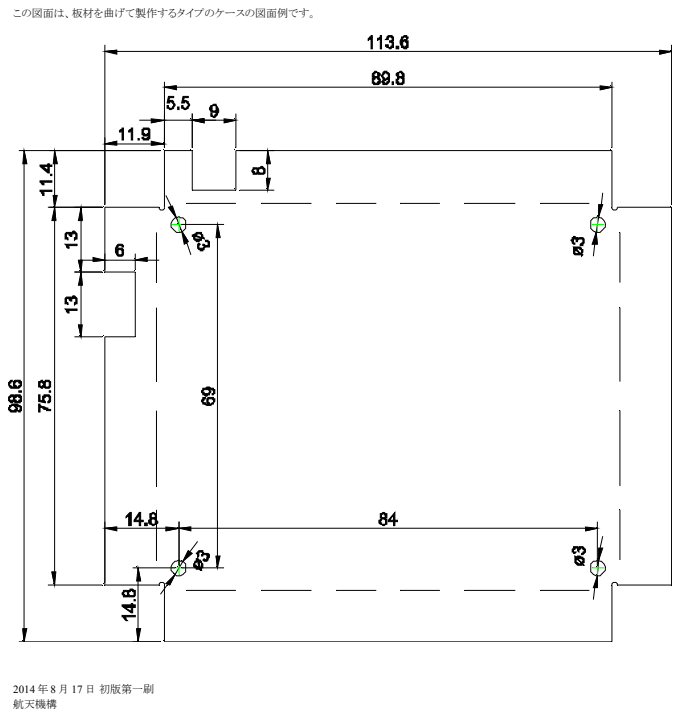
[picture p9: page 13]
この図面は、板材を曲げて製作するタイプのケースの図面例です。; 2014 年 8 月 17 日 初版第一刷 航天機構

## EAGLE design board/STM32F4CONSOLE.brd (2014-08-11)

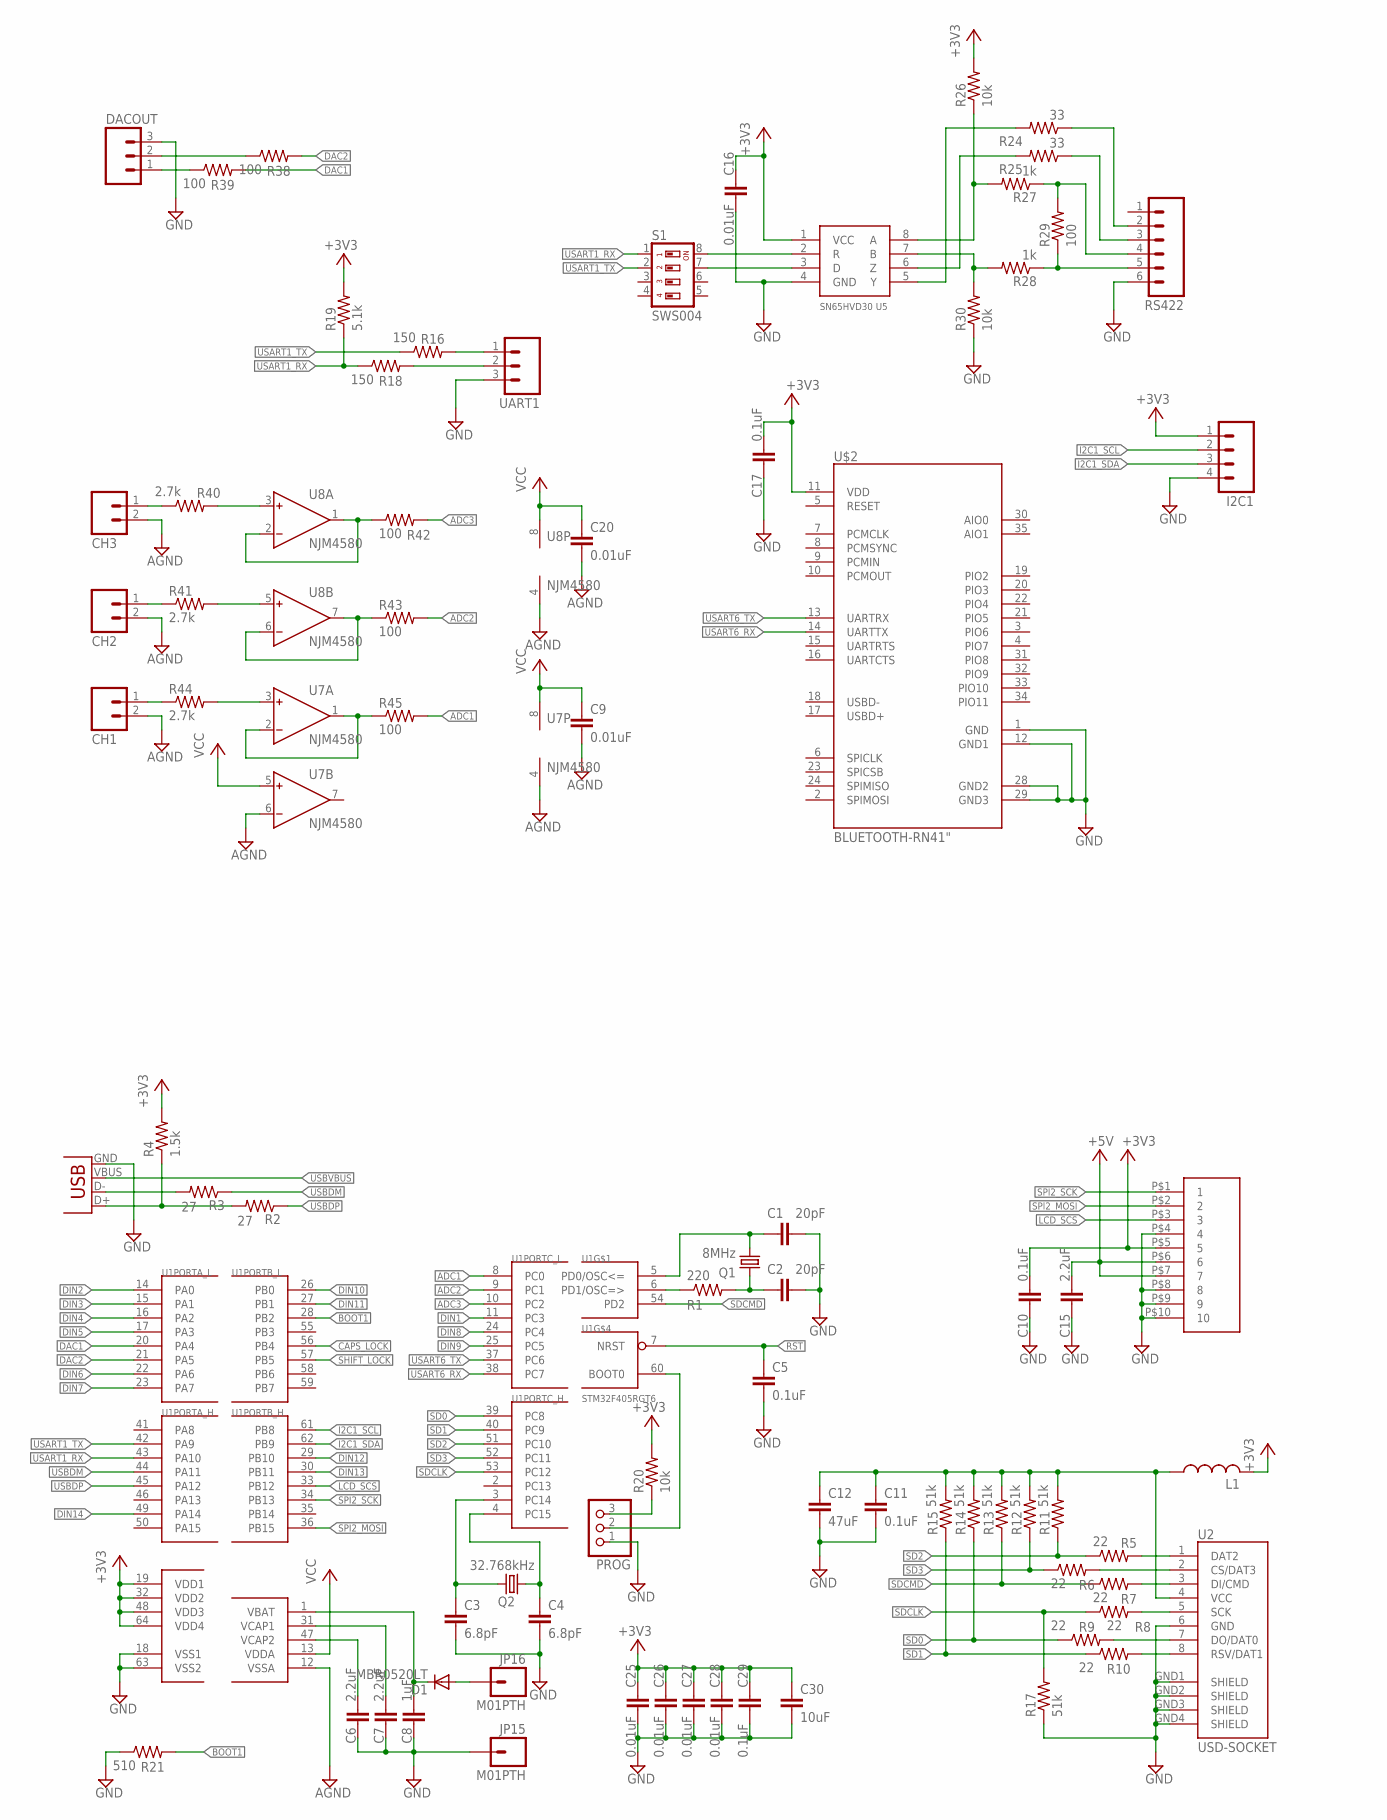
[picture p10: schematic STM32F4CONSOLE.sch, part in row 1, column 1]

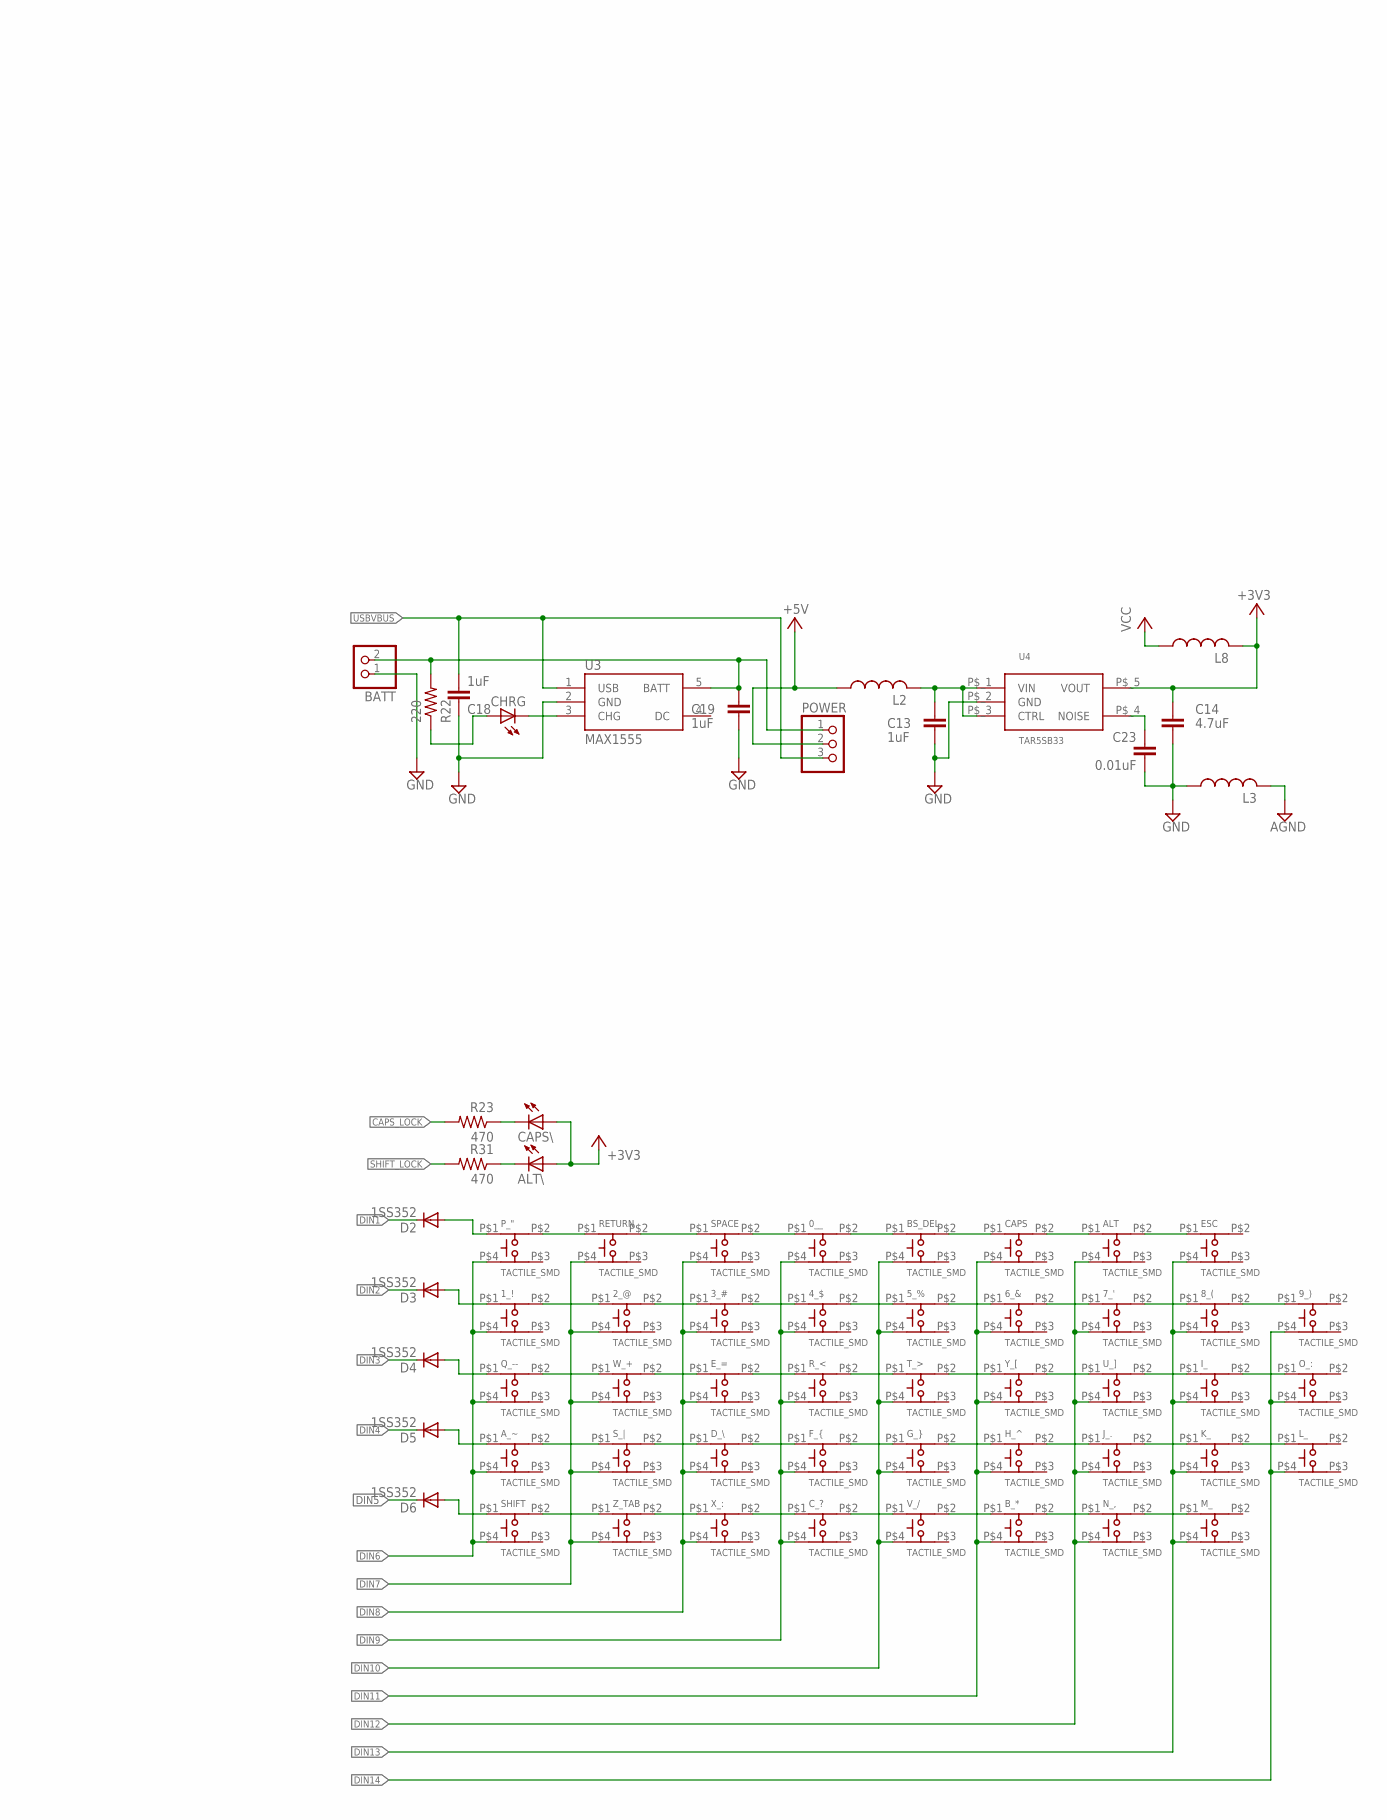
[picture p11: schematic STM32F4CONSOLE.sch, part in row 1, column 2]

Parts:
0__, 1_!, 2_@, 3_#, 4_$, 5_%, 6_&, 7_', 8_(, 9_): TACTILE_SMD
ALT: TACTILE_SMD
ALT\: LED0603; LED-0603
A_~: TACTILE_SMD
BATT: PINHD-1X2; 1X02
BS_DEL: TACTILE_SMD
B_*: TACTILE_SMD
C1, C2: 20pF; C0603
C3, C4: 6.8pF; C0603
C5, C10, C11, C17, C29: 0.1uF; C0603
C6, C7, C15: 2.2uF; C0805
C8: 1uF; C1608
C9, C16, C20, C23, C25, C26, C27, C28: 0.01uF; C0603
C12: 47uF; C3225
C13, C18, C19: 1uF; C2012
C14: 4.7uF; C2012
C30: 10uF; C3216
CAPS: TACTILE_SMD
CAPS\: LED0603; LED-0603
CH1, CH2, CH3: M02PTH; 1X02
CHRG: LED0603; LED-0603
C_?: TACTILE_SMD
D1: MBR0520LT; SOD123
D2, D3, D4, D5, D6: 1SS352; SOD-323
DACOUT: M03PTH; 1X03
D_\\: TACTILE_SMD
ESC: TACTILE_SMD
E_=: TACTILE_SMD
F_{: TACTILE_SMD
G_}: TACTILE_SMD
H_^: TACTILE_SMD
I2C1: M04PTH; 1X04
I_: TACTILE_SMD
JP15, JP16: M01PTH; 1X01
J_.: TACTILE_SMD
K_: TACTILE_SMD
L1, L2, L3, L8: L-USL3216C; L3216C
L_: TACTILE_SMD
M_: TACTILE_SMD
N_,: TACTILE_SMD
O_:: TACTILE_SMD
POWER: PINHD-1X3; 1X03
PROG: PINHD-1X3; 1X03
P_": TACTILE_SMD
Q1: 8MHz; HC49/S
Q2: 32.768kHz; TC26H
Q_--: TACTILE_SMD
R1, R22: 220; R0603
R2, R3: 27; R0603
R4: 1.5k; R0603
R5, R6, R7, R8, R9, R10: 22; R0603
R11, R12, R13, R14, R15, R17: 51k; R0603
R16, R18: 150; R0603
R19: 5.1k; R0603
R20, R26, R30: 10k; R0603
R21: 510; R0603
R23, R31: 470; R0603
R24, R25: 33; R0603
R27, R28: 1k; R0603
R29, R38, R39, R42, R43, R45: 100; R0603
R40, R41, R44: 2.7k; R0805
RETURN: TACTILE_SMD
RS422: M06SIP; 1X06
R_<: TACTILE_SMD
S1: SWS004; SMSS-004
SHIFT: TACTILE_SMD
SPACE: TACTILE_SMD
S_|: TACTILE_SMD
T_>: TACTILE_SMD
U1: STM32F405RGT6; TQFP64
U2: USD-SOCKET; MICRO-SD-SOCKET-PP
U3: MAX1555; SOT23-5
U4: TAR5SB33
U5: SN65HVD30; SO8
U6: FH12-10S-05; FH12-10S-0.5SH
U7, U8: NJM4580; SO08
U$2: BLUETOOTH-RN41"; RN41
UART1: M03PTH; 1X03
U_]: TACTILE_SMD
V_/: TACTILE_SMD
W_+: TACTILE_SMD
X1: USBOLD; USB-MINIB-OLD
X_:: TACTILE_SMD
Y_[: TACTILE_SMD
Z_TAB: TACTILE_SMD

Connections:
+3V3: ALT\.A, C10.1, C14.1, C16.1, C17.1, C25.1, C26.1, C27.1, C28.1, C29.1, C30.1, CAPS\.A, I2C1.1, L1.2, L8.2, R4.2, R19.2, R20.2, R26.2, U1.19 (VDD1), U1.32 (VDD2), U1.48 (VDD3), U1.64 (VDD4), U4.P$_5 (VOUT), U5.1 (VCC), U6.P$5 (5), U$2.11 (VDD)
+5V: C15.1, L2.1, POWER.2, U6.P$6 (6), U6.P$7 (7)
ADC1: R45.2, U1.8 (PC0)
ADC2: R43.2, U1.9 (PC1)
ADC3: R42.2, U1.10 (PC2)
AGND: C9.2, C20.2, CH1.2, CH2.2, CH3.2, L3.2, U1.12 (VSSA), U7.4 (V-), U7.6 (IN-), U8.4 (V-)
BOOT1: R21.2, U1.28 (PB2)
CAPS_LOCK: R23.2, U1.56 (PB4)
DAC1: R39.2, U1.20 (PA4)
DAC2: R38.2, U1.21 (PA5)
DIN1: D2.1 (C), U1.11 (PC3)
DIN2: D3.1 (C), U1.14 (PA0)
DIN3: D4.1 (C), U1.15 (PA1)
DIN4: D5.1 (C), U1.16 (PA2)
DIN5: D6.1 (C), U1.17 (PA3)
DIN6: 1_!.P$4, A_~.P$4, P_".P$4, Q_--.P$4, SHIFT.P$4, U1.22 (PA6)
DIN7: 2_@.P$4, RETURN.P$4, S_|.P$4, U1.23 (PA7), W_+.P$4, Z_TAB.P$4
DIN8: 3_#.P$4, D_\\.P$4, E_=.P$4, SPACE.P$4, U1.24 (PC4), X_:.P$4
DIN9: 0__.P$4, 4_$.P$4, C_?.P$4, F_{.P$4, R_<.P$4, U1.25 (PC5)
DIN10: 5_%.P$4, BS_DEL.P$4, G_}.P$4, T_>.P$4, U1.26 (PB0), V_/.P$4
DIN11: 6_&.P$4, B_*.P$4, CAPS.P$4, H_^.P$4, U1.27 (PB1), Y_[.P$4
DIN12: 7_'.P$4, ALT.P$4, J_..P$4, N_,.P$4, U1.29 (PB10), U_].P$4
DIN13: 8_(.P$4, ESC.P$4, I_.P$4, K_.P$4, M_.P$4, U1.30 (PB11)
DIN14: 9_).P$4, L_.P$4, O_:.P$4, U1.49 (PA14)
DIN_2: 6_&.P$2, 7_'.P$1
DIN_3: I_.P$2, O_:.P$1
DIN_4: J_..P$2, K_.P$1
DIN_5: B_*.P$2, N_,.P$1
GND: BATT.1, C1.2, C2.2, C3.2, C4.2, C5.2, C6.2, C7.2, C8.2, C10.2, C11.2, C12.2, C13.2, C14.2, C15.2, C16.2, C17.2, C18.2, C19.2, C23.2, C25.2, C26.2, C27.2, C28.2, C29.2, C30.2, DACOUT.3, I2C1.4, JP15.1, L3.1, PROG.1, R17.1, R21.1, R30.1, RS422.6, U1.18 (VSS1), U1.63 (VSS2), U2.6 (GND), U2.GND1 (SHIELD), U2.GND2 (SHIELD), U2.GND3 (SHIELD), U2.GND4 (SHIELD), U3.2 (GND), U4.P$_2 (GND), U5.4 (GND), U6.P$4 (4), U6.P$8 (8), U6.P$9 (9), U6.P$10 (10), U$2.1 (GND), U$2.12 (GND1), U$2.28 (GND2), U$2.29 (GND3), UART1.3, X1.GND
I2C1_SCL: I2C1.2, U1.61 (PB8)
I2C1_SDA: I2C1.3, U1.62 (PB9)
LCD_SCS: U1.33 (PB12), U6.P$3 (3)
unnamed: R1.1, U1.6 (PD1/OSC=>)
unnamed: C2.1, Q1.1, R1.2
unnamed: C1.1, Q1.2, U1.5 (PD0/OSC<=)
unnamed: C6.1, U1.47 (VCAP2)
unnamed: C7.1, U1.31 (VCAP1)
unnamed: C4.1, Q2.2, U1.4 (PC15)
unnamed: C3.1, Q2.1, U1.3 (PC14)
unnamed: C8.1, D1.C, U1.1 (VBAT)
unnamed: R5.2, U2.1 (DAT2)
unnamed: R6.2, U2.2 (CS/DAT3)
unnamed: R7.2, U2.3 (DI/CMD)
unnamed: D1.A, JP16.1
unnamed: R8.2, U2.5 (SCK)
unnamed: R9.2, U2.7 (DO/DAT0)
unnamed: R10.2, U2.8 (RSV/DAT1)
unnamed: BATT.2, C19.1, POWER.1, R22.2, U3.5 (BATT)
unnamed: R3.2, X1.D-
unnamed: R2.2, R4.1, X1.D+
unnamed: R18.2, UART1.2
unnamed: R16.2, UART1.1
unnamed: PROG.2, U1.60 (BOOT0)
unnamed: C13.1, L2.2, U4.P$_1 (VIN), U4.P$_3 (CTRL)
unnamed: CHRG.A, R22.1
unnamed: CHRG.C, U3.3 (CHG)
unnamed: D2.2 (A), P_".P$1
unnamed: P_".P$2, RETURN.P$1
unnamed: RETURN.P$2, SPACE.P$1
unnamed: 0__.P$1, SPACE.P$2
unnamed: C11.1, C12.1, L1.1, R11.2, R12.2, R13.2, R14.2, R15.2, U2.4 (VCC)
unnamed: 0__.P$2, BS_DEL.P$1
unnamed: 1_!.P$1, D3.2 (A)
unnamed: 1_!.P$2, 2_@.P$1
unnamed: D6.2 (A), SHIFT.P$1
unnamed: SHIFT.P$2, Z_TAB.P$1
unnamed: C23.1, U4.P$_4 (NOISE)
unnamed: X_:.P$1, Z_TAB.P$2
unnamed: C_?.P$1, X_:.P$2
unnamed: C_?.P$2, V_/.P$1
unnamed: A_~.P$2, S_|.P$1
unnamed: F_{.P$2, G_}.P$1
unnamed: CH3.1, R40.1
unnamed: DACOUT.1, R39.1
unnamed: DACOUT.2, R38.1
unnamed: R40.2, U8.3 (IN+)
unnamed: CH2.1, R41.1
unnamed: R41.2, U8.5 (IN+)
unnamed: R43.1, U8.6 (IN-), U8.7 (OUT)
unnamed: R42.1, U8.1 (OUT), U8.2 (IN-)
unnamed: CH1.1, R44.1
unnamed: R44.2, U7.3 (IN+)
unnamed: R45.1, U7.1 (OUT), U7.2 (IN-)
unnamed: PROG.3, R20.1
unnamed: D_\\.P$2, F_{.P$1
unnamed: D_\\.P$1, S_|.P$2
unnamed: A_~.P$1, D5.2 (A)
unnamed: D4.2 (A), Q_--.P$1
unnamed: Q_--.P$2, W_+.P$1
unnamed: E_=.P$1, W_+.P$2
unnamed: E_=.P$2, R_<.P$1
unnamed: R_<.P$2, T_>.P$1
unnamed: 2_@.P$2, 3_#.P$1
unnamed: 3_#.P$2, 4_$.P$1
unnamed: 4_$.P$2, 5_%.P$1
unnamed: BS_DEL.P$2, CAPS.P$1
unnamed: ALT.P$1, CAPS.P$2
unnamed: ALT.P$2, ESC.P$1
unnamed: S1.7, U5.3 (D)
unnamed: S1.8, U5.2 (R)
unnamed: R24.2, U5.5 (Y)
unnamed: 8_(.P$2, 9_).P$1
unnamed: 7_'.P$2, 8_(.P$1
unnamed: 5_%.P$2, 6_&.P$1
unnamed: T_>.P$2, Y_[.P$1
unnamed: U_].P$1, Y_[.P$2
unnamed: I_.P$1, U_].P$2
unnamed: K_.P$2, L_.P$1
unnamed: R25.2, U5.6 (Z)
unnamed: M_.P$1, N_,.P$2
unnamed: B_*.P$1, V_/.P$2
unnamed: G_}.P$2, H_^.P$1
unnamed: H_^.P$2, J_..P$1
unnamed: R28.2, R30.2, U5.7 (B)
unnamed: R26.1, R27.2, U5.8 (A)
unnamed: R28.1, R29.1, RS422.5
unnamed: R27.1, R29.2, RS422.4
unnamed: R25.1, RS422.3
unnamed: R24.1, RS422.2
unnamed: CAPS\.C, R23.1
unnamed: ALT\.C, R31.1
RST: C5.1, U1.7 (NRST)
SD0: R9.1, R14.1, U1.39 (PC8)
SD1: R10.1, R15.1, U1.40 (PC9)
SD2: R5.1, R11.1, U1.51 (PC10)
SD3: R6.1, R12.1, U1.52 (PC11)
SDCLK: R8.1, R17.2, U1.53 (PC12)
SDCMD: R7.1, R13.1, U1.54 (PD2)
SHIFT_LOCK: R31.2, U1.57 (PB5)
SPI2_MOSI: U1.36 (PB15), U6.P$2 (2)
SPI2_SCK: U1.34 (PB13), U6.P$1 (1)
USART1_RX: R18.1, R19.1, S1.1, U1.43 (PA10)
USART1_TX: R16.1, S1.2, U1.42 (PA9)
USART6_RX: U1.38 (PC7), U$2.14 (UARTTX)
USART6_TX: U1.37 (PC6), U$2.13 (UARTRX)
USBDM: R3.1, U1.44 (PA11)
USBDP: R2.1, U1.45 (PA12)
USBVBUS: C18.1, POWER.3, U3.1 (USB), X1.VBUS
VCC: C9.1, C20.1, L8.1, U1.13 (VDDA), U7.5 (IN+), U7.8 (V+), U8.8 (V+)

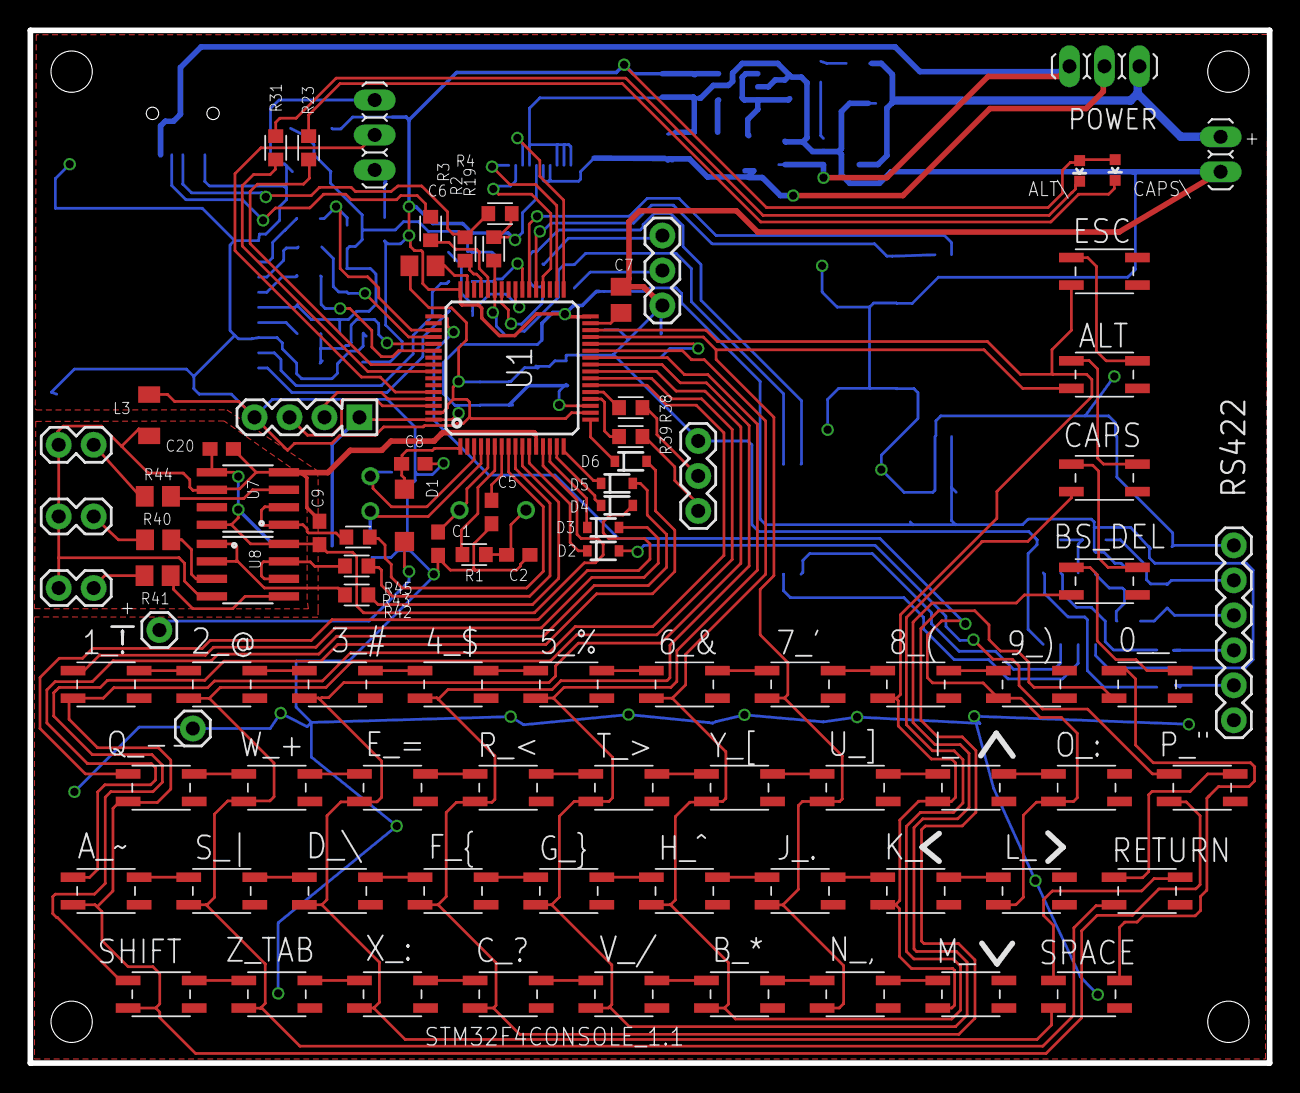
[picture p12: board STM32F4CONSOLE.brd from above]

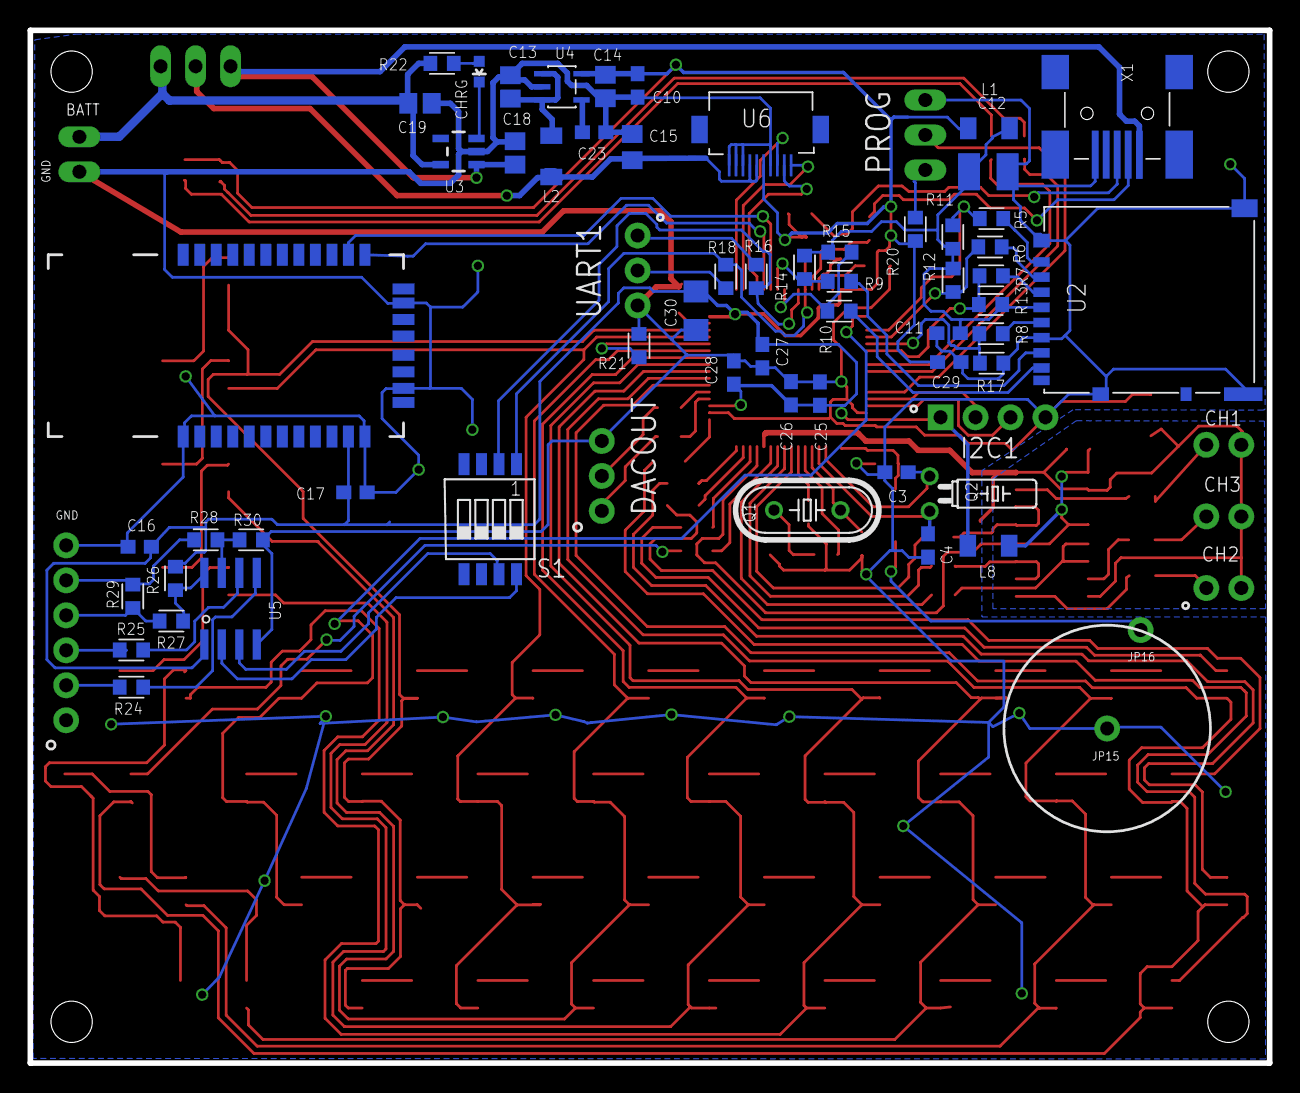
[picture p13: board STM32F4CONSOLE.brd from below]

Board: 2 copper layers, 90.0 x 75.0 mm, 147 parts (57 on the bottom side), 139 nets.

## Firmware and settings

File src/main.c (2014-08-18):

#include "stm32f4xx.h"
#include "platform_config.h"
#include "hw_config.h"
#include "stm32f4xx_dcmi.h"
#include "glcd.h"
#ifdef USE_KANJI
#include "libnkf.h"
#endif
#include "editor.h"
#include "ubasic.h"

//#ifdef USE_USB
#include "usbd_msc_core.h"
#include "usbd_usr.h"
#include "usbd_desc.h"
#include "usb_conf.h"
//#endif

#ifdef USE_MRUBY
#include "mruby.h"
#include "mruby/proc.h"
#endif

//#ifdef USE_USB
__ALIGN_BEGIN USB_OTG_CORE_HANDLE  USB_OTG_dev __ALIGN_END;
//#endif

#define  MORPHY 0
#define  GRAPHIC_TEST 1
#define  ADC_FIFO 400

const int stepY = 28;
const int offsetYC = 16;
const int stepYA = 100;
const int offsetYCA = 7;
const int offsetYH = 16+3;
const int offsetYL = 16+24;

uint8_t fifoa1[ADC_FIFO];
uint8_t fifoa2[ADC_FIFO];
uint16_t fifo_in;

void _exit(int n) {
label:  goto label; /* endless loop */
}

void fifo_clear()
{
	int i;
	fifo_in = 0;
	for (i = 0;i < ADC_FIFO;i++) {
		fifoa1[i] = 0;
		fifoa2[i] = 0;
	}
}

uint8_t getData(void)
{
//	DIN1:PC3 DIN2:PA0 DIN3:PA1 DIN4:PA2
//	DIN5:PA3 DIN6:PA6 DIN7:PA7 DIN8:PC4

	uint8_t pa,pc,r;
	pa = GPIO_ReadInputData(GPIOA);
	pc = GPIO_ReadInputData(GPIOC);
	r = (pa << 1) & 0x1e;
	r |= ((pa >> 1) & 0x60);
	r |= ((pc >> 3) & 0x01);
	r |= ((pc << 3) & 0x80);
	return r;
}

uint16_t divMS = 5;
uint16_t divC = 1;

void getDataHandler(void)
{
	static uint16_t c = 1;
	if(--c) return;
	c = divC;
//	fifo[fifo_in] = getData();
	if (fifo_in >= ADC_FIFO)fifo_in = 0;

	if (ADC_GetFlagStatus(ADC1, ADC_FLAG_EOC) == RESET) {
		fifoa1[fifo_in] = 0xff;
	} else {
		fifoa1[fifo_in] = ADC_GetConversionValue(ADC1) & 0x00ff;
		ADC_SoftwareStartConv(ADC1);
	}
	if (ADC_GetFlagStatus(ADC2, ADC_FLAG_EOC) == RESET){
		fifoa2[fifo_in] = 0xff;
	} else {
		fifoa2[fifo_in] = ADC_GetConversionValue(ADC2) & 0x00ff;
		ADC_SoftwareStartConv(ADC2);
	}
	fifo_in++;
	if (fifo_in >= ADC_FIFO)fifo_in = 0;
}


DWORD acc_size;
WORD acc_files, acc_dirs;
FILINFO Finfo;
DIR  dir;
//FATFS Fatfs[_VOLUMES];
FATFS Fatfs;
FIL fileR[2];
// BYTE Buff[BUFSIZE] __attribute__ ((aligned (4))) ;
__IO uint8_t Command_index = 0;
UINT nTextFile; // TXT ファイルの数
FATFS *fs;  /* Pointer to file system object */

#if _USE_LFN
char Lfname[512];
#endif

uint32_t get_fattime (void)
{
  uint32_t res;
  /* See rtc_support.h */
  RTC_GetTime(RTC_Format_BIN, &RTC_TimeStructure);  
  RTC_GetDate(RTC_Format_BIN, &RTC_DateStructure);
  
  res =  (( (uint32_t)ts_year + (2000 - 1980)) << 25)
      | ((uint32_t)(ts_mon) << 21)
      | ((uint32_t)ts_mday << 16)
      | (uint32_t)(ts_hour << 11)
      | (uint32_t)(ts_min << 5)
      | (uint32_t)(ts_sec);
  return res;
}

static void put_rc (FRESULT rc)
{
  const char *str =
    "OK\0" "DISK_ERR\0" "INT_ERR\0" "NOT_READY\0" "NO_FILE\0" "NO_PATH\0"
    "INVALID_NAME\0" "DENIED\0" "EXIST\0" "INVALID_OBJECT\0" "WRITE_PROTECTED\0"
    "INVALID_DRIVE\0" "NOT_ENABLED\0" "NO_FILE_SYSTEM\0" "MKFS_ABORTED\0" "TIMEOUT\0"
    "LOCKED\0" "NOT_ENOUGH_CORE\0" "TOO_MANY_OPEN_FILES\0";
  FRESULT i;

  for (i = 0; i != rc && *str; i++) {
    while (*str++) ;
  }
  glcd_Puts(" rc=");
  glcd_PutsUint((UINT)rc);
  glcd_Puts("FR_");
  glcd_Puts(str);
  glcd_Puts("\r\n");
}

static void put_rcD (FRESULT rc)
{
  const char *str =
    "OK\0" "DISK_ERR\0" "INT_ERR\0" "NOT_READY\0" "NO_FILE\0" "NO_PATH\0"
    "INVALID_NAME\0" "DENIED\0" "EXIST\0" "INVALID_OBJECT\0" "WRITE_PROTECTED\0"
    "INVALID_DRIVE\0" "NOT_ENABLED\0" "NO_FILE_SYSTEM\0" "MKFS_ABORTED\0" "TIMEOUT\0"
    "LOCKED\0" "NOT_ENOUGH_CORE\0" "TOO_MANY_OPEN_FILES\0";
  FRESULT i;

  for (i = 0; i != rc && *str; i++) {
    while (*str++) ;
  }
  glcd_PutsD("FR_");
  glcd_PutsD(str);
  glcd_PutsD("\n");
}

static FRESULT scan_files (
  char* path /* Pointer to the path name working buffer */
)
{
  DIR dirs;
  FRESULT res;
  BYTE i;
  char *fn;
  if ((res = f_opendir(&dirs, path)) == FR_OK) {
    i = strlen(path);
    while (((res = f_readdir(&dirs, &Finfo)) == FR_OK) && Finfo.fname[0]){
      if (_FS_RPATH && Finfo.fname[0] == '.') continue;
#if _USE_LFN
      fn = *Finfo.lfname ? Finfo.lfname : Finfo.fname;
#else
      fn = Finfo.fname;
#endif
      if (Finfo.fattrib & AM_DIR) {
        acc_dirs++;
        *(path+i) = '/';
        strcpy(path+i+1, fn);
        res = scan_files(path);
        *(path+i) = '\0';
        if (res != FR_OK) break;
      } else {
        acc_files++;
        acc_size += Finfo.fsize;
      }
    }
  }
  return res;
}

FRESULT initSD()
{
  BYTE res;
  long p2;
  static const BYTE ft[] = {0, 12, 16, 32};

#if _USE_LFN
  Finfo.lfname = Lfname;
  Finfo.lfsize = sizeof(Lfname);
#endif
  f_mount(&Fatfs, "", 1);
//  f_mount(0, &Fatfs[0]);
  glcd_Puts(" _MAX_SS : ");
  glcd_PutsInt(_MAX_SS);
  glcd_Puts("\r\n");
  glcd_Puts(" FatFs module test terminal for ");
  glcd_Puts(MPU_SUBMODEL);
  glcd_Puts("\r\n");
  glcd_Puts(_USE_LFN ? " LFN Enabled" : " LFN Disabled");
  glcd_Puts(", Code page: ");
  glcd_PutsUint(_CODE_PAGE);
  glcd_Puts("\r\n");
  res = f_getfree("", (DWORD*)&p2, &fs);
  if (res) {
    put_rc(res);
  } else {
   	glcd_Puts(" FAT type = FAT");
    glcd_PutsUint(ft[fs->fs_type & 3]);
   	glcd_Puts("\r\n Bytes/Cluster = ");
    glcd_PutsUint((DWORD)fs->csize * 512);
   	glcd_Puts("\r\n Number of FATs = ");
    glcd_PutsUint((WORD)fs->n_fats);
   	glcd_Puts("\r\n");
   	glcd_Puts(" Root DIR entries = ");
    glcd_PutsUint(fs->n_rootdir);
   	glcd_Puts("\r\n Sectors/FAT = ");
    glcd_PutsInt(fs->fsize);
   	glcd_Puts("\r\n Number of clusters ="); 
    glcd_PutsInt((DWORD)fs->n_fatent - 2);
   	glcd_Puts("\r\n");
   	glcd_Puts(" FAT start (lba) = ");
    glcd_PutsInt(fs->fatbase);
   	glcd_Puts("\r\n DIR start (lba,clustor) = ");
    glcd_PutsInt(fs->dirbase);
   	glcd_Puts("\r\n Data start (lba) = ");
    glcd_PutsInt(fs->database);
   	glcd_Puts("\r\n\r\n ...");
    acc_size = acc_files = acc_dirs = 0;
    Finfo.lfname = Lfname;
    Finfo.lfsize = sizeof(Lfname);
    res = scan_files("");
    if (res) {
      put_rc(res);
    } else {
      glcd_Puts("\r\n ");
      glcd_PutsUint(acc_files);
      glcd_Puts(" files,"); 
      glcd_PutsInt(acc_size);
      glcd_Puts("bytes.\r\n ");
      glcd_PutsUint(acc_dirs);
      glcd_Puts(" folders.\r\n ");
      glcd_PutsInt((fs->n_fatent - 2) * (fs->csize / 2));
      glcd_Puts(" KB total disk space.\r\n ");
      glcd_PutsInt(p2 * (fs->csize / 2));
      glcd_Puts(" KB available.\r\n");
    }
  }
  return res;
}


FRESULT lsSDA()
{
	BYTE res;
	DIR dirs;
	res = f_opendir(& dirs, "");
	if (res) {
		put_rcD(res);
	} else {
		for(;;) {
			res = f_readdir(& dirs, &Finfo);
			if ((res != FR_OK) || !Finfo.fname[0]) break;
			glcd_PutsD(" ");
			glcd_PutsD((Finfo.fattrib & AM_DIR) ? ("D"):("-"));
			glcd_PutsD((Finfo.fattrib & AM_RDO) ? ("R"):("-"));
			glcd_PutsD((Finfo.fattrib & AM_HID) ? ("H"):("-"));
			glcd_PutsD((Finfo.fattrib & AM_SYS) ? ("S"):("-"));
			glcd_PutsD((Finfo.fattrib & AM_ARC) ? ("A"):("-"));
			glcd_PutsD(" ");
			glcd_PutsUint8D((Finfo.fdate >> 9) + 1980);
			glcd_PutsD("/");
			glcd_PutsUint8D((Finfo.fdate >> 5) & 15);
			glcd_PutsD("/");
			glcd_PutsUint8D(Finfo.fdate & 31);
			glcd_PutsD(" ");
			glcd_PutsUint8D(Finfo.ftime >> 11);
			glcd_PutsD(":");
			glcd_PutsUint8D((Finfo.ftime >> 5) & 63);
			glcd_PutsD(" ");
			glcd_PutsUint8D(Finfo.fsize);
			glcd_PutsD("  ");
			glcd_PutsD(&(Finfo.fname[0]));
			glcd_PutsD("\n");
		}
		f_closedir(&dirs);
	}
	return res;
}

FRESULT lsSD()
{
  BYTE res;
  long p1, p2;
  UINT s1, s2;
  res = f_getfree("", (DWORD*)&p2, &fs);// testcode
  res = f_opendir(& dir, "");
  if (res) {
    put_rc(res);
  } else {
    p1 = s1 = s2 = 0;
    nTextFile = 0;
    for(;;) {
      res = f_readdir(& dir, &Finfo);
      if ((res != FR_OK) || !Finfo.fname[0]) break;
      if (Finfo.fattrib & AM_DIR) {
        s2++;
      } else {
        s1++; p1 += Finfo.fsize;
        if (isEx(&(Finfo.fname[0]),"TXT")) {
          nTextFile++;
        }
      }
      glcd_Puts(" ");
      glcd_PutChar((Finfo.fattrib & AM_DIR) ? (0x8000|'D'):(0x8000|'-'));
      glcd_PutChar((Finfo.fattrib & AM_RDO) ? (0x8000|'R'):(0x8000|'-'));
      glcd_PutChar((Finfo.fattrib & AM_HID) ? (0x8000|'H'):(0x8000|'-'));
      glcd_PutChar((Finfo.fattrib & AM_SYS) ? (0x8000|'S'):(0x8000|'-'));
      glcd_PutChar((Finfo.fattrib & AM_ARC) ? (0x8000|'A'):(0x8000|'-'));
      glcd_PutChar(0x8000 | ' ');
      glcd_PutsUint((Finfo.fdate >> 9) + 1980);
      glcd_PutChar(0x8000 | '/');
      glcd_PutsUint8((Finfo.fdate >> 5) & 15);
      glcd_PutChar(0x8000 | '/');
      glcd_PutsUint8(Finfo.fdate & 31);
      glcd_PutChar(0x8000 | ' ');
      glcd_PutsUint8(Finfo.ftime >> 11);
      glcd_PutChar(0x8000 | ':');
      glcd_PutsUint8((Finfo.ftime >> 5) & 63);
      glcd_PutChar(0x8000 | ' ');
      glcd_PutsInt(Finfo.fsize);
      glcd_Puts("  ");
      glcd_Puts(&(Finfo.fname[0]));
#if _USE_LFN
      for (p2 = strlen(Finfo.fname); p2 < 14; p2++)
       	glcd_Puts(" ");
      glcd_Puts(Lfname);
      glcd_Puts("\r\n");
#else
      glcd_Puts("\r\n");
#endif
    }
   	glcd_Puts(" "); 
    glcd_PutsUint(s1);
   	glcd_Puts(" File(s),"); 
    glcd_PutsInt(p1);
   	glcd_Puts(" bytes total\r\n ");
    glcd_PutsUint(s2);
   	glcd_Puts("  dir(s)");
    res = f_getfree("", (DWORD*)&p1, &fs);
    if (res == FR_OK) {
     	glcd_Puts(", ");
		if (p1 * fs->csize/2 > (1024 * 1024)) {
		  glcd_PutsInt(p1 * fs->csize /(2048*1-24));
     	  glcd_Puts(" Mbytes free\r\n");
		} else 
		if (p1 * fs->csize/2 > 1024) {
		  glcd_PutsInt(p1 * fs->csize /2048);
     	  glcd_Puts(" k bytes free\r\n");
		} else {
		  glcd_PutsInt(p1 * fs->csize /2);
     	  glcd_Puts(" k bytes free\r\n");
		}
    } else {
      put_rc(res);
    }
   	glcd_Puts(" TXT File ");
    glcd_PutsUint(nTextFile);
   	glcd_Puts("\r\n");
  }
  return res;
}

FIL file;
#define FBUF_SIZE 512		// SDカードへ書き込むためのバッファサイズ
#define RING_BUF_SIZE 8
uint8_t ring_buffer[RING_BUF_SIZE][FBUF_SIZE];
volatile uint8_t ring_buffer_p_in  = 0;
volatile uint8_t ring_buffer_p_out = 0;
UINT pBuf = 0;
UINT flgSDcard = 0;

void putcSD(uint8_t data)
{
	ring_buffer[ring_buffer_p_in][pBuf] = data;
	pBuf++;
	if (pBuf >= FBUF_SIZE) {
		pBuf = 0;
		ring_buffer_p_in ++;
		if (ring_buffer_p_in >= RING_BUF_SIZE) {
			ring_buffer_p_in = 0;
		}
	}
}

void initADC();

uint8_t d[8];
uint8_t f[8];

char input_str[1024];
int input_p,input_k;
#ifdef USE_KANJI
char output_str[1536];
#endif
int flgChangeGLCD = 0;

uint8_t psw;
#ifdef USE_BLUETOOTH_HID
enum eDISP_STATUS { BASIC, ANALOGIN, SERIALIN, BLUEKEYBOARD, CLOCKSETTING };
#else
enum eDISP_STATUS { BASIC, ANALOGIN, SERIALIN, CLOCKSETTING };
#endif
enum eDISP_STATUS disp_status = BASIC;
uint8_t flgTRIG = 1;

uint16_t tmp_year;
uint8_t tmp_mon,tmp_day;
uint8_t tmp_hour,tmp_min,tmp_sec;
uint8_t cs;

#ifdef SERIAL_DEBUG
int serial_debug_c = 0;
#endif

char program[] = "10 cls \n20 print \"MODE BASIC\"\n30 print \"OK\"\n40 end\n";

int main(void)
{
	int i,j,n,t,x;
	uint16_t c;
	UINT fbuflen;
	
#ifdef USE_MRUBY
  mrb_state *mrb = NULL;
  extern const uint8_t appbin[];
#endif
	
//	bv = RTC_ReadBackupRegister(RTC_BKP_DR2);
	/* Set Basis System */
	Set_System();
	/* Set SysTickCounter for _delay_ms(); */
	SysTickInit(INTERVAL);

	initADC();
	fifo_clear();
	glcd_Init();
	glcd_BufClear(1);
	glcd_posClear();
//	conio_init(UART_DEFAULT_NUM,UART_BAUDLATE);
	conio_init(6,115200);/*Bluetooth*/

	input_p = 0;
	input_k = 0;
	flgChangeGLCD = 0;
	RTC_Configuration(0);
	set_RTC(2014,8,17,12,00,0);


	glcd_x = 0;
	glcd_y = 0;
	flgUpdate = 1;
	initSD();

	USBD_Init(&USB_OTG_dev,
            USB_OTG_FS_CORE_ID,
            &USR_desc,
            &USBD_MSC_cb, 
            &USR_cb);
            
	_delay_ms(100);

	glcd_clearEditor();
	glcd_DrawCursor_first();
	ubasic_init(program);

	_delay_ms(100);


#ifdef USE_MRUBY
	/* initialize mruby */
	mrb = mrb_open();
	/* start mruby application */
	mrb_load_irep(mrb, appbin);
	if (mrb->exc) {
		mrb_p(mrb, mrb_obj_value(mrb->exc));
	}
	/* finalize mruby */
	mrb_close(mrb);
#endif


	glcd_TransFromBuf();
	flgSDcard = 0;
	for (i = 0;i < 30;i++) {
		glcd_TransFromBuf();
		if(CmdKey != 0x00)i=30;
		_delay_ms(10);
	}

	/* Main Loop */
	while (1)
	{
		glcd_TransFromBuf();
		if(CmdKey == 0x1B){/*ESC*/
			CmdKey = 0;
			disp_status ++;
			if (disp_status > CLOCKSETTING) {
				disp_status = BASIC;
				glcd_BufClear(1);
				glcd_posClear();
				ubasic_init(program);
			}
			if (disp_status == SERIALIN) {
				glcd_BufClear(1);
				glcd_x = 0;
				glcd_y = 0;
				flgUpdate = 0;
			//	cputs_p(6,"$$$ SM,0 S~,0 R,1\r");
				glcd_PutsD("MODE SERIAL\n");
				_delay_ms(200);
			}
#ifdef USE_BLUETOOTH_HID
			if (disp_status == BLUEKEYBOARD) {
				glcd_BufClear(1);
				glcd_x = 0;
				glcd_y = 0;
				flgUpdate = 0;
				cputs_p(6,"$$$ S~,6 SM,6 SH,0200 R,1\r");
				_delay_ms(200);
				glcd_PutsD("MODE BLUETOOTH KEYBOARD\n");
			}
#endif
			if (disp_status == CLOCKSETTING) {
				RTC_GetTime(RTC_Format_BIN, &RTC_TimeStructure);  
				RTC_GetDate(RTC_Format_BIN, &RTC_DateStructure);
				tmp_year=2000+ts_year;
				tmp_mon=ts_mon;
				tmp_day=ts_mday;
				tmp_hour=ts_hour;
				tmp_min=ts_min;
				tmp_sec=ts_sec;
				cs = 0;
			}
		}
		if (disp_status == CLOCKSETTING) {
			if((c = kgetc()) != 0){
				if((c == 'K')||(c == 'k')||(c == KEY_LEFT)){
					cs--;
					if(cs < 0)cs = 5;
				}else if((c == 'L')||(c == 'l')||(c == KEY_RIGHT)){
					cs++;
					if(cs >= 6)cs = 0;
				}
				if((c == 'M')||(c == 'm')||(c == KEY_DOWN)){
					switch (cs) {
						case 0:
							tmp_year --;
							break;
						case 1:
							tmp_mon --;
							if(tmp_mon == 0) {
								tmp_mon = 12;
							}
							break;
						case 2:
							tmp_day --;
							if(tmp_day == 0) {
								tmp_day = 31;
							}
							break;
						case 3:
							if(tmp_hour == 0) {
								tmp_hour =23;
							} else {
								tmp_hour --;
							}
							break;
						case 4:
							if(tmp_min == 0) {
								tmp_min =59;
							} else {
								tmp_min --;
							}
							break;
						case 5:
							if(tmp_sec == 0) {
								tmp_sec =59;
							} else {
								tmp_sec --;
							}
							break;
					}
				}
				if((c == 'I')||(c == 'i')||(c == KEY_UP)){
					switch (cs) {
						case 0:
							tmp_year ++;
							break;
						case 1:
							tmp_mon ++;
							if(tmp_mon == 13) {
								tmp_mon = 1;
							}
							break;
						case 2:
							tmp_day ++;
							if(tmp_day == 32) {
								tmp_day = 1;
							}
							break;
						case 3:
							if(tmp_hour == 23) {
								tmp_hour = 0;
							} else {
								tmp_hour ++;
							}
							break;
						case 4:
							if(tmp_min == 59) {
								tmp_min = 0;
							} else {
								tmp_min ++;
							}
							break;
						case 5:
							if(tmp_sec == 59) {
								tmp_sec = 0;
							} else {
								tmp_sec ++;
							}
							break;
					}
				}
				if(c == '\n'){
					RTC_Configuration(1);
					set_RTC(tmp_year,tmp_mon,tmp_day,tmp_hour,tmp_min,tmp_sec);
				}
			}
		}
		if (disp_status == ANALOGIN) {
			if(CmdKey == 0x05){/*CURSOR*/
				flgTRIG ++;
				if (flgTRIG > 2){
					flgTRIG = 0;
				}
			}
			if(CmdKey == 0x08){/*BS_DEL*/
				switch (divMS) {
					case 5:
						break;
					case 10:
						divMS = 5;
						divC = 1;
						fifo_clear();
						break;
					case 20:
						divMS = 10;
						divC = 2;
						fifo_clear();
						break;
					case 50:
						divMS = 20;
						divC = 4;
						fifo_clear();
						break;
					case 100:
						divMS = 50;
						divC = 10;
						fifo_clear();
						break;
					case 200:
						divMS = 100;
						divC = 20;
						fifo_clear();
						break;
					case 500:
						divMS = 200;
						divC = 40;
						fifo_clear();
						break;
					case 1000:
						divMS = 500;
						divC = 100;
						fifo_clear();
						break;
				}
			}
			if(CmdKey == 0x02){/*CAPS_NUM*/
				switch (divMS) {
					case 5:
						divMS = 10;
						divC = 2;
						fifo_clear();
						break;
					case 10:
						divMS = 20;
						divC = 4;
						fifo_clear();
						break;
					case 20:
						divMS = 50;
						divC = 10;
						fifo_clear();
						break;
					case 50:
						divMS = 100;
						divC = 20;
						fifo_clear();
						break;
					case 100:
						divMS = 200;
						divC = 40;
						fifo_clear();
						break;
					case 200:
						divMS = 500;
						divC = 100;
						fifo_clear();
						break;
					case 500:
						divMS = 1000;
						divC = 200;
						fifo_clear();
						break;
					case 1000:
						break;
				}
			} 
		}
		if ((disp_status != SERIALIN)
#ifdef USE_BLUETOOTH_HID
			&&(disp_status != BLUEKEYBOARD)
#endif
			&&(disp_status != BASIC)) {
			glcd_BufClear(1);
			glcd_posClear();
		}
		switch (disp_status) {
			case BASIC:
				if(ubasic_finished() == 0){
					ubasic_run();
				}else{
					if((c = kgetc()) != 0){
						if(glcd_PutEditor(c)){
						//	glcd_PutsA(LINEBUF);
						//	ubasic_init(LINEBUF);
						}
					}
				}
				break;
			case ANALOGIN:
				for (i = 0;i < 2;i++) {
					glcd_PutCharAt(8,i*stepYA+offsetYCA+stepYA/2,0x8000|('1'+i));
					glcd_PutCharAt(16,i*stepYA+offsetYCA+stepYA/2,0x8000|'c');
					glcd_PutCharAt(24,i*stepYA+offsetYCA+stepYA/2,0x8000|'h');
				}
				j = -divMS;
				for (i = 32;i < 400;i += 50) {
					glcd_Vline(i,j);
					j += divMS;
				}
				if (flgTRIG == 0) {
					t = fifo_in - 400;
					if (t < 0) t += ADC_FIFO;
				} else {
					t = fifo_in - 800;
					if (t < 0) t += ADC_FIFO;
					if (flgTRIG == 1) {
						while ((t != fifo_in) && (fifoa1[t] >= 0x80)) {
							t++;
							if (t >= ADC_FIFO) t = 0;
						}
						while ((t != fifo_in) && (!(fifoa1[t] >= 0x80))) {
							t++;
							if (t >= ADC_FIFO) t = 0;
						}
						if (t == fifo_in) {
							t = fifo_in - 400;
							if (t < 0) t += ADC_FIFO;
						} else {
							t = t - 42;
							if (t < 0) t += ADC_FIFO;
						}
					} else {
						while ((t != fifo_in) && (!(fifoa1[t] >= 0x80))) {
							t++;
							if (t >= ADC_FIFO) t = 0;
						}
						while ((t != fifo_in) && (fifoa1[t] >= 0x80)) {
							t++;
							if (t >= ADC_FIFO) t = 0;
						}
						if (t == fifo_in) {
							t = fifo_in - 400;
							if (t < 0) t += ADC_FIFO;
						} else {
							t = t - 42;
							if (t < 0) t += ADC_FIFO;
						}
					}
				}
				for (x = 40;x < 400;x++) {
					glcd_setDot(x,1*stepYA+offsetYCA-fifoa1[t]/3);
					glcd_setDot(x,2*stepYA+offsetYCA-fifoa2[t]/3);
					t++;
					if (t >= ADC_FIFO) t = 0;
				}
				break;
			case SERIALIN:
#ifdef USE_BLUETOOTH_HID
			case BLUEKEYBOARD:
#endif
				if((c = kgetc()) != 0){
					if(c == 0x1B){/*ESC*/
						
					}else{
						glcd_PutChar(c | 0x8000);
				//		putch_p(6,c);/*Send Bluetooth*/
						putch_p(1,c);/*Send UART1*/
						if(c == 0x0d){
							glcd_PutChar(0x0a | 0x8000);
				//			putch_p(6,0x0a);/*Send Bluetooth*/
							putch_p(1,0x0a);/*Send UART1*/
						}
					}
				}
			//	if((c = getch_p16(6)) != 0xffff){/*Rcv Bluetooth*/
				if((c = getch_p16(1)) != 0xffff){/*Rcv UART1*/
					glcd_PutChar(c | 0x8000);
				}
				break;
			case CLOCKSETTING:
				glcd_PutsAt(48,70,"Clock setting");
				RTC_GetTime(RTC_Format_BIN, &RTC_TimeStructure);  
				RTC_GetDate(RTC_Format_BIN, &RTC_DateStructure);
				glcd_Dec(120,94,4,2000+ts_year,1);
				glcd_PutCharAt(120+8*4,94,0x8000|'/');
				glcd_Dec(120+8*5,94,2,ts_mon,1);
				glcd_PutCharAt(120+8*7,94,0x8000|'/');
				glcd_Dec(120+8*8,94,2,ts_mday,1);
				glcd_PutCharAt(120+8*10,94,0x8000|' ');
				glcd_Dec(120+8*11,94,2,ts_hour,1);
				glcd_PutCharAt(120+8*13,94,0x8000|':');
				glcd_Dec(120+8*14,94,2,ts_min,1);
				glcd_PutCharAt(120+8*16,94,0x8000|':');
				glcd_Dec(120+8*17,94,2,ts_sec,1);
				glcd_Dec(120,110,4,tmp_year,cs != 0);
				glcd_PutCharAt(120+8*4,110,0x8000|'/');
				glcd_Dec(120+8*5,110,2,tmp_mon,cs != 1);
				glcd_PutCharAt(120+8*7,110,0x8000|'/');
				glcd_Dec(120+8*8,110,2,tmp_day,cs != 2);
				glcd_PutCharAt(120+8*10,110,0x8000|' ');
				glcd_Dec(120+8*11,110,2,tmp_hour,cs != 3);
				glcd_PutCharAt(120+8*13,110,0x8000|':');
				glcd_Dec(120+8*14,110,2,tmp_min,cs != 4);
				glcd_PutCharAt(120+8*16,110,0x8000|':');
				glcd_Dec(120+8*17,110,2,tmp_sec,cs != 5);
			default:
				break;
		}
		input_k++;
		while((input_p < 1000) && ((c = getch_p16(6)) != 0xffff)){
			if (flgChangeGLCD == 0) flgChangeGLCD = 2;
			putcSD(c);
			input_str[input_p++] = c;
			if ((c == '\r') || (c == '\n')) {
				if (disp_status == SERIALIN) {
					// UNIX系 は    LFのみ
					// WINDOWS系 は CR LF
					// MAC系 は     CRのみ
					// LF: 0x0A \n Control-J
					// CR: 0x0D \r Control-M
					if (c == '\n') { // UNIX用の修正
						input_str[input_p-1] = '\r';
						input_str[input_p++] = '\n';
					}
					input_str[input_p++] = 0;
#ifdef USE_KANJI
					nkf(input_str, output_str, 1024, "-jW");
					glcd_Puts_Serial(output_str);
#else
					glcd_Puts_Serial(input_str);
#endif
				}
				input_p = 0;
			}
			input_k = 0;
		}
		if (disp_status == SERIALIN) {
			if ((input_p > 0) && (2 < input_k)) {
				input_str[input_p++] = 0;
#ifdef USE_KANJI
				nkf(input_str, output_str, 1024, "-jW");
				glcd_Puts_Serial(output_str);
#else
				glcd_Puts_Serial(input_str);
#endif
				input_p = 0;
				glcd_transChar();
				flgChangeGLCD = 0;
			}
			if((flgChangeGLCD) && (2 < input_k)) {
				glcd_transChar();
				flgChangeGLCD = 0;
			} else if(flgChangeGLCD == 1) {
				glcd_transChar();
				flgChangeGLCD = 0;
			} else if(flgChangeGLCD > 0) {
				flgChangeGLCD--;
			}
		}

		if (input_p >= 1000)
			input_p = 0;

		if (flgSDcard) {
			if (input_k > 100) { // 10 秒以上シリアル入力が無い時
				while(pBuf) putcSD('\n');
				input_k = 0;
			}
			n = ring_buffer_p_in - ring_buffer_p_out;
			if (n < 0) {
				n += RING_BUF_SIZE;
			}
			if (((input_k > 0) && (n > 0)) || (n > (RING_BUF_SIZE - 2))) {
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

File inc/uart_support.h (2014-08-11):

/*
 UART2TX : PA2
 UART2RX : PA3
 UART3TX : PD8
 UART3RX : PD9
 UART4TX : PA0
 UART4RX : PA1
 UART6TX : PC6
 UART6RX : PC7
*/



#ifndef __UART_SUPPORT_H
#define __UART_SUPPORT_H

#ifdef __cplusplus
 extern "C" {
#endif

/* General Inclusion */
#include <stdio.h>
#include <stdlib.h>
#include <string.h>
#include <stdbool.h>
#include <inttypes.h>

/* uC Specific Inclusion */
#include "stm32f4xx.h"
#include "stm32f4xx_it.h"
#include "stm32f4xx_conf.h"

/* USART Definition */
#define UART_BUFSIZE		256
//#define UART_BAUDLATE		9600UL
//#define UART_BAUDLATE		115200UL
#define UART_BAUDLATE		38400UL
#define UART_DEFAULT_NUM	1 /*USART2 PA2,PA3 default use*/

/* General Definition */
#define countof(a)   (sizeof(a) / sizeof(*(a)))

/* Funcion Prototypes */
extern void conio_init(uint32_t port, uint32_t baudrate);
extern void set_defalt_cino_port(uint32_t port);
extern void putch(uint8_t c);
extern void putch_p(uint32_t port,uint8_t c);
extern uint8_t getch(void);
extern uint8_t getch_p(uint32_t port);
extern uint16_t getch_p16(uint32_t port);
extern uint8_t keypressed(uint32_t port);
extern void cputs(char *s);
extern void cputs_p(uint32_t, char *);
extern void cgets(uint32_t port,char *s, int bufsize);

/* Structs */
/* This is From AVRX uC Sample!!! */
/* @brief USART transmit and receive ring buffer. */
typedef struct USART_Buffer
{
	/* @brief Receive buffer. */
	volatile uint8_t RX[UART_BUFSIZE];
	/* @brief Transmit buffer. */
	volatile uint8_t TX[UART_BUFSIZE];
	/* @brief Receive buffer head. */
	volatile uint16_t RX_Head;
	/* @brief Receive buffer tail. */
	volatile uint16_t RX_Tail;
	/* @brief Transmit buffer head. */
	volatile uint16_t TX_Head;
	/* @brief Transmit buffer tail. */
	volatile uint16_t TX_Tail;
} USART_Buffer_t;

/* Externs */
extern USART_Buffer_t USART1_Buf;
extern USART_Buffer_t USART2_Buf;
extern USART_Buffer_t USART3_Buf;
extern USART_Buffer_t UART4_Buf;
extern USART_Buffer_t USART6_Buf;

#ifdef __cplusplus
}
#endif

#endif	/* __UART_SUPPORT_H */

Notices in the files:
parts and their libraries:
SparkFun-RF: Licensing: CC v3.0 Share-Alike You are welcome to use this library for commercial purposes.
